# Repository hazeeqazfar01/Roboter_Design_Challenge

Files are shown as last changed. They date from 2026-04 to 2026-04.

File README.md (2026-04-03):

# Roboter Design Challenge 2025 @ Jade Hochschule
https://www.jade-hs.de/unsere-hochschule/fachbereiche/ingenieurwissenschaften/veranstaltungen/design-challenge/

**Team Members:** Isma, Syahir, and Hazeeq

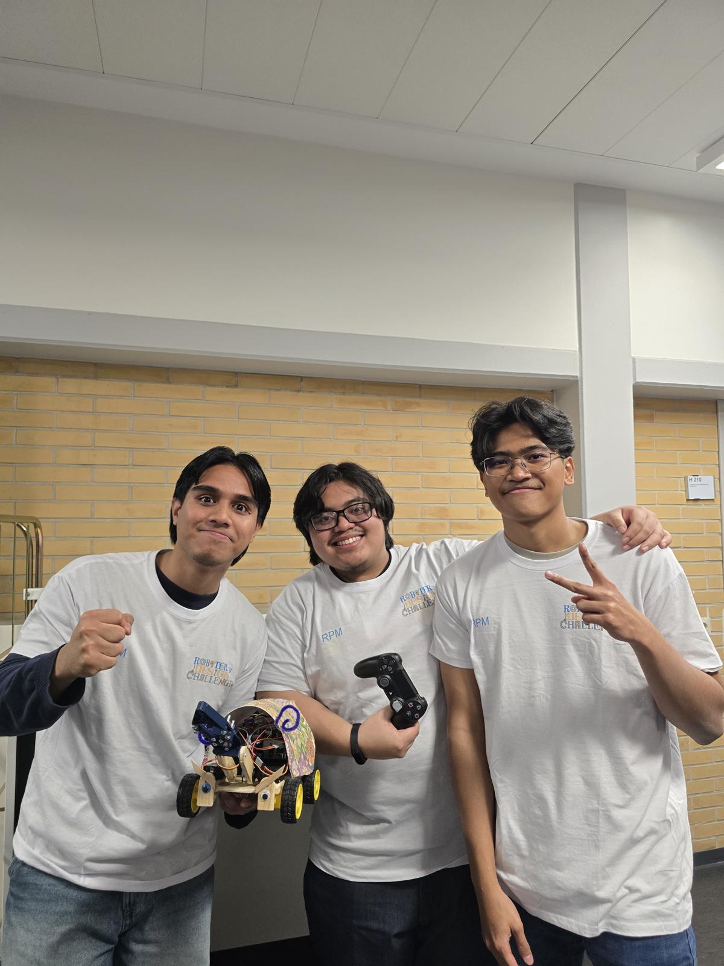
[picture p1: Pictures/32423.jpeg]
Project Picture

---
https://www.nwzonline.de/wilhelmshaven/karrieretag-in-wilhelmshaven-jade-hochschule-begeistert-800-besucher-mit-einblicken-in-studium-und-beruf_a_4,2,2852570350.html#
---

This repository contains documents, project materials, and results from our participation in the **Roboter Design Challenge 2025**.

Dieses Repository enthält Unterlagen, Dokumentationen und Projektergebnisse unserer Teilnahme an der **Roboter Design Challenge 2025**.

---

## Deutsch

### Über den Wettbewerb
Die Roboter Design Challenge 2025 steht unter dem Motto eines Katastrophenszenarios in der Stadt Wilhelmshaven. Ziel ist die Entwicklung und Programmierung eines Roboters, der in einer modellhaften Stadt Hilfs- und Transportaufgaben übernimmt.

### Aufgabenstellung
Die Teams erhalten einen vom Roboter Design Challenge Team bereitgestellten Bausatz, aus dem nach den geltenden Regeln ein funktionsfähiger Roboter konstruiert wird. Bei Bedarf kann der Roboter mit eigenen Teilen ergänzt werden.

### Projektinhalt
Dieses Repository enthält projektbezogene Unterlagen und Dateien aus verschiedenen Arbeitsbereichen, zum Beispiel:
- Entwurfsphasen
- Programmierung
- Report
- Regelwerk
- Weitere Projektdokumente

### Unsere Arbeit
Im Rahmen des Projekts arbeiteten wir an der Planung, Konstruktion, Dokumentation und Organisation des Robotersystems.

---

## English

### About the Competition
The Roboter Design Challenge 2025 is based on a disaster scenario in the city of Wilhelmshaven. The goal is to design and program a robot that can carry out aid and transport tasks in a model city environment.

### Task Description
Each team receives a kit provided by the Roboter Design Challenge team. According to the competition rules, this kit is used to construct a functional robot. If necessary, the robot can be extended with additional custom parts.

### Project Contents
This repository includes project-related documents and files from different work areas, such as:
- Design phases
- Programming
- Report
- Rules and regulations
- Additional project documents

### Our Work
As part of this project, we worked on the planning, construction, documentation, and organization of the robotic system.

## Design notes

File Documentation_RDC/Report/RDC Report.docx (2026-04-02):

Robotic Design Challenge

By RPM

Gruppe | RPM
Gruppenmitglieder (Name, Vorname, Matrikelnummer) | Muhammad Syahir Irshad Bin Mohd Sharuddin - 6056209
| Muhammad Isma Haikal bin Ismail – 6057561
| Muhammad Hazeeq Azfar bin Herman 6055724

# 1. Einleitung

Die Roboter Design Challenge 2025 steht unter dem Motto eines schweren Katastrophenszenarios in der Stadt Wilhelmshaven. Ein Sturm hat große Schäden angerichtet: Stromleitungen sind zerstört, Hilfsgüter müssen schnell geliefert werden und zahlreiche Menschen benötigen medizinische Hilfe.

Die Teams erhalten einen vorgegebenen Bausatz und entwickeln daraus – unter Einhaltung der Regeln – einen funktionsfähigen Roboter, der bei Bedarf mit eigenen Bauteilen erweitert werden darf. Auf einem Spielfeld im Miniaturformat der Stadt müssen die Roboter verschiedene Aufgaben bewältigen.

In den Wettbewerbsrunden stehen drei zentrale Herausforderungen im Mittelpunkt:

- Stromversorgung wiederherstellen: Die Teams müssen eine beschädigte Stromleitung finden und reparieren. Die Bewertung erfolgt nach Zeit.
- Hilfsgütertransport: dringend benötigte Güter werden vom Deich zum Krankenhaus transportiert und korrekt abgelegt. Schnellste Teams bzw. Teams mit den meisten Gütern kommen weiter.
- Personenrettung: Figuren in den Farben Rot, Gelb und Grün – entsprechend dem Manchester Triage System – müssen sicher geborgen und zum Behandlungsplatz gebracht werden. Je nach Dringlichkeit gibt es unterschiedliche Punktzahlen, Bonuspunkte bei besonders schneller Rettung.

Diese Szenarien verlangen ein Robotersystem, das zuverlässig fährt, transportiert, erkennt, greift und Präzisionsaufgaben ausführt – Fähigkeiten, die im Mittelpunkt unseres Projekts stehen.

# 2. Ziel des Projekts

Ziel dieses Projekts ist es, ein Roboter zu entwickeln, das den Anforderungen und Einsatzbedingungen entspricht

Dafür wird eine methodische Vorgehensweise genutzt, die sich an bewährten Schritten im Konstruktionsprozess orientiert. Dazu gehören: das Erstellen einer Anforderungsliste, das Entwickeln einer Funktionsstruktur, das Finden grundsätzlicher Lösungsansätze, die Bewertung möglicher Varianten sowie eine Risikobetrachtung. Diese strukturierte Vorgehensweise sorgt dafür, dass der Roboter passend zur Aufgabenstellung entworfen wird.

# 3. Anforderungsliste

Die Anforderungsliste wurde im Rahmen einer vorgegebenen Aufgabenstellung gemeinsam entwickelt. Die Liste dient als verbindliche Planungsgrundlage für die weitere Ausarbeitung des Entwurfs. Durch die gemeinsame Bearbeitung wurde sichergestellt, dass alle ein einheitliches Verständnis der Anforderungen besitzen und diese im Konstruktionsprozess konsequent berücksichtigt werden.

Tabelle1: Die gemeinsame Aufforderungsliste für den Entwurf

Kategorie | Anforderung | Detail | F/W
FAHREN | • Muss über unebenes Gelände und Rampen (Steigung max.10 Grad) fahren können (Geländegängigkeit). | • Fahrwerk muss stabil sein (gegen Wackeln/Kippen). | F
| • Muss sich in engen Raum drehen und wenden können. | • Darf die Maße 24×19×45 cm niemals überschreiten. | F
GELD/PERSONEN | • Muss die Hilfsgüter−Box und die Personen−Figuren aufnehmen können. | • Der Greifarm/Mechanismus muss präzise genug sein, um kleine Figuren zu fassen. | F
| • Muss die Objekte während der Fahrt sicher halten (Transportschutz). | • Die 3 Servos und 4 Motoren müssen optimal für Bewegung und Greifen genutzt werden. | F
| • Muss die Stromversorgung (Hebel/Schalter) betätigen können. | | F
WETTKAMPF | • Muss sehr zuverlässig sein (damit es wenig Eingriffe gibt: ≤4 Eingriffe erlaubt). | • Die Elektronik muss sicher und einfach zugänglich sein für schnelle Reparaturen. | F
| • Wunsch: Muss schnell genug sein, um alle Personen in ≤6 Minuten zu retten (Bonus!). | | W
PROGRAMMIERUNG | • Die Steuerung muss präzise sein, damit Sie den Roboter gut kontrollieren können. | • durch den Einsatz von ESP32, H-Brücken und Kontroller | F

# 4. Projektablauf

Damit der Entwurf termingerecht und strukturiert ausgearbeitet werden könnte, wurde ein Gantt-Diagramm erstellt. Es dient dazu, den zeitlichen Ablauf des Projekts übersichtlich darzustellen und die einzelnen Arbeitsschritte sowie deren Abhängigkeiten zu planen und zu koordinieren.

Tabelle 2: Der gesamte Projektablauf in der Form Gantt-Diagramm für den Entwurf

Nr. | Vorgangs-name | 13.10 | 15.10 | 18.10 | 20.10 | 20.10 | 23.04 | 26.10 | 28.10 | 29.10 | 06.11 | 9.11 | 10.11 | 15 .11 | 16.11 | 18.11 | 19.11
1 | Bausätze abholen
2 | Phase 1
3 | Projektzeitplan erstellen
4 | Roboter Recherchieren
5 | Lösungen finden
6 | Ideen finalisieren
8 | Phase 2
9 | Schaltplan verstehen
10 | 3D Teil suchen
11 | Löten
12 | Phase 3
13 | Holz bearbeiten
14 | Bauteile kaufen
15 | Anfangen zu programmieren
16 | Roboter konstruieren
17 | Phase 4
18 | Programmierung
19 | Debugging
20 | Dokumentation erstellen
21 | Zulassung für Wettbewerb
22 | Tag des Wettbewerbes

# 5. Mechanisches Konzept und Roboter Komponenten

## 5.1. Aufbau

### Bodenplatte

Sie bildet die zentrale Trägerstruktur des gesamten Roboters. Auf ihr werden alle elektrischen und mechanischen Komponenten befestigt. Sie sorgt für Stabilität, Gewichtsausgleich und eine geordnete Platzierung von Steuerplatine, Versorgungsmodulen, Motoren und Armmechanik. Sie besteht aus Holz, wobei besonders auf Steifigkeit und geringes Gewicht geachtet wird.

### Greifer

Er ist das mechanische Element, das es dem Roboter ermöglicht, Objekte aufzunehmen, festzuhalten und zu transportieren. Er wird meist durch ein oder zwei Servomotoren angetrieben, die für präzise Bewegungen sorgen. Je nach Konstruktion kann der Greifer parallel schließen, klemmen oder zangenartig greifen.

### Roboterarm

Er verbindet die Bodenplatte mit dem Greifer und sorgt dafür, dass dieser in unterschiedliche Positionen bewegt werden kann. Üblicherweise ist der Arm mehrgliedrig aufgebaut, ähnlich wie ein menschlicher Arm mit Schulter-, Ellenbogen- und Handgelenksbewegung. Die Antriebe erfolgen durch Servomotoren oder Getriebemotoren. Der Arm muss leicht genug sein, damit die Motoren nicht überlastet werden, gleichzeitig jedoch steif und stabil, um präzise Bewegungen und eine gewisse Traglast zu gewährleisten.

### Reifen

Sie sind für die Fortbewegung des Roboters verantwortlich. Gummierte oder profilierte Räder sorgen für eine gute Traktion auf verschiedenen Untergründen, während der Durchmesser des Reifens die Geschwindigkeit und die Fähigkeit bestimmt, kleinere Hindernisse zu überwinden. Die Reifen sind direkt oder über eine Getriebeuntersetzung mit den DC-Motoren verbunden, wodurch Antriebskraft und Bewegungspräzision beeinflusst werden.

### Akkupack

Es versorgt alle Komponenten des Roboters zuverlässig mit Energie. Der Akku muss eine ausreichende Kapazität sowie einen ausreichenden Entladestrom bereitstellen, damit Motoren, Servos und Mikrocontroller stabil betrieben werden können. Über die Versorgungsplatine wird die Spannung geregelt und sicher auf die einzelnen Verbraucher verteilt.

## 5.2. Funktion

Der in diesem Projekt entwickelte Robote dient zur gezielten Manipulation von kleinen Objekten in einem vorgebebenen Spielfeld. Er würde im Rahmen eine Design Challenge entworfen, konstruiert und programmiert, um grundlegende Prinzipien von Aktuator- und Elektro- und Steuerungstechnik in der Praxis umzusetzen.

Die Bewegung dieser Roboterarm würden durch Einsetzen mehrere Servomotoren erreicht, die eine präzise Positionierung des Endeffektors ermöglichen. Für dieses Projekt würden zwei SG5010 Servomotoren und eine SG90 Servomotor, die ein ausreichendes Drehmoment liefern, verwendet, damit sowohl leichte Bauteile als auch kleineren Lasten zuverlässig bewegen werden können.

Die Funktionen dieses Motors lassen sich anhand einiger Punkten beschreiben. Diese Funktionen umfassen die für den Challenge vorgegebene Aufgabe sowie einige weitere, die hinzugefügt wurden, um unsere Fähigkeiten in diesen Bereichen weiter auszubauen und zu verfeinern. Die Funktionen lassen sich wie folgt beschreiben:

- Objektaufnahme: Der Greifer öffnet und schließen kontrolliert, um kleine Objekte sicher zu erfassen, ohne zu beschädigen.
- Objekttransport: Der Roboterarm bewegt das gegriffene Objekt mithilfe des Drehgelenks im Roboterarm.
- Objektablage: Das Objekt wird an der gewünschten Position präzise abgelegt, unterstutzt durch die fein gesteuerte Greiferbewegungen.
- Joysticksteuerung (PS4- Controller): Die Taste im Kontrolle steuern alle Bewegungen des Robotes, wie die Vorwärts- und Rückwärtsbewegung, Rotationsbewegung, Drehung des Gelenkes und das Öffnen und Schließen des Greifers.
- Lastaufnahme im vorgesehenen Bereich: kann kleine Werkstücke im Rahmen von 100g Gewicht zuverlässig aufnehmen und stabil halten.
- Funktionssicherheit: Die Elektronik schützt von Fehlerfunktionen wie Überlast oder falscher Motoransteuerung, wodurch ein sicherer Betrieb gewährleistet sind.

In Verbindung mit diesen Funktionen kann das Projekt eine angemessene Richtung in seiner Entwicklung einschlagen und den Fortschritt bis zur Fertigstellung des Projektes beschleunigen. Mit ihrer Hilfe wird der Roboter in einige Hauptfunktion unterteilt, die bei der Entscheidung über die Konstruktion und Bau des Roboters im Mittelpunkt stehen werden.

## 5.3. Handskizzen

Für den Entwurf des Roboters werden verschiedene Lösungen mit unterschiedlicher Charakteristisch hergestellt. Die Vielfalt der Ideen dients als Standarddiskussionsmedium, um die beste und geeignetste Lösung zu finden.

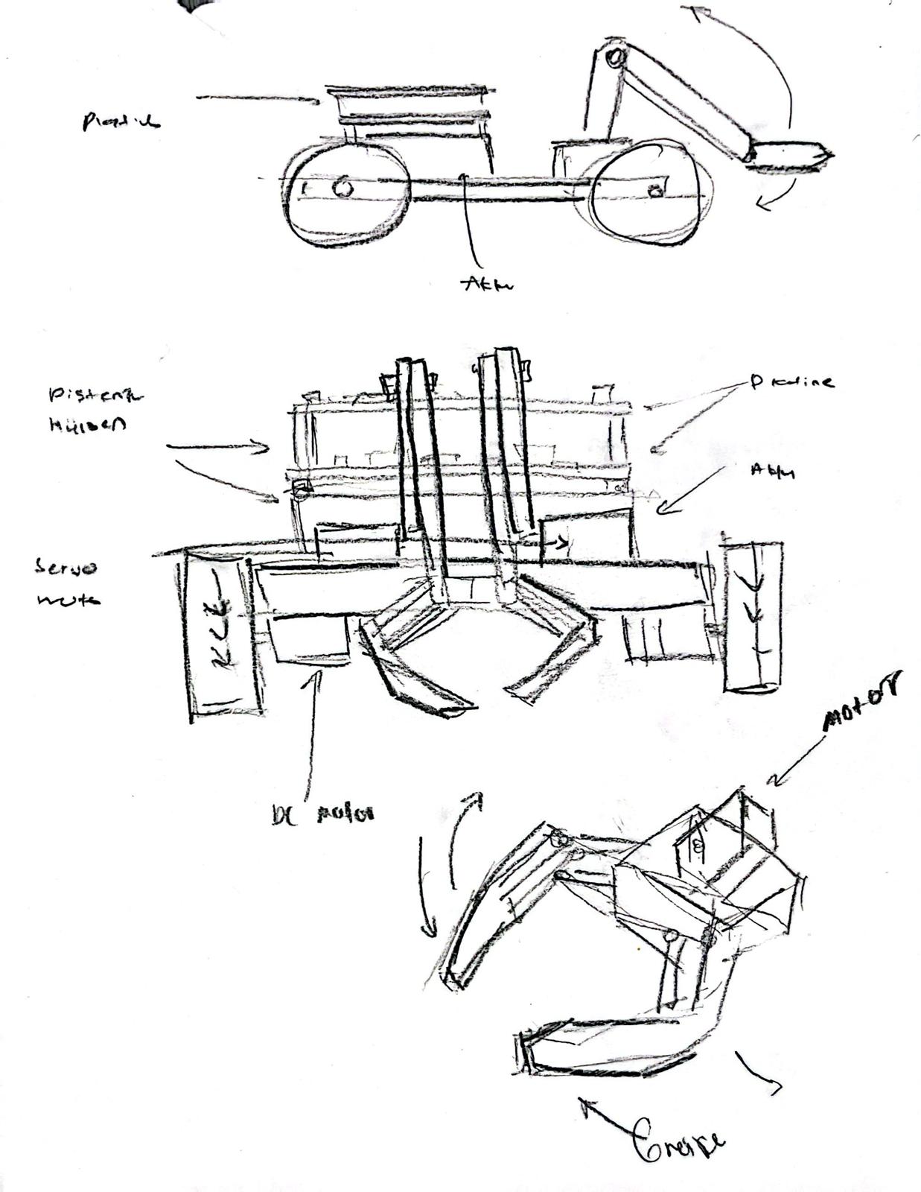
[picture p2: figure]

Abbildung 1: Variante 1

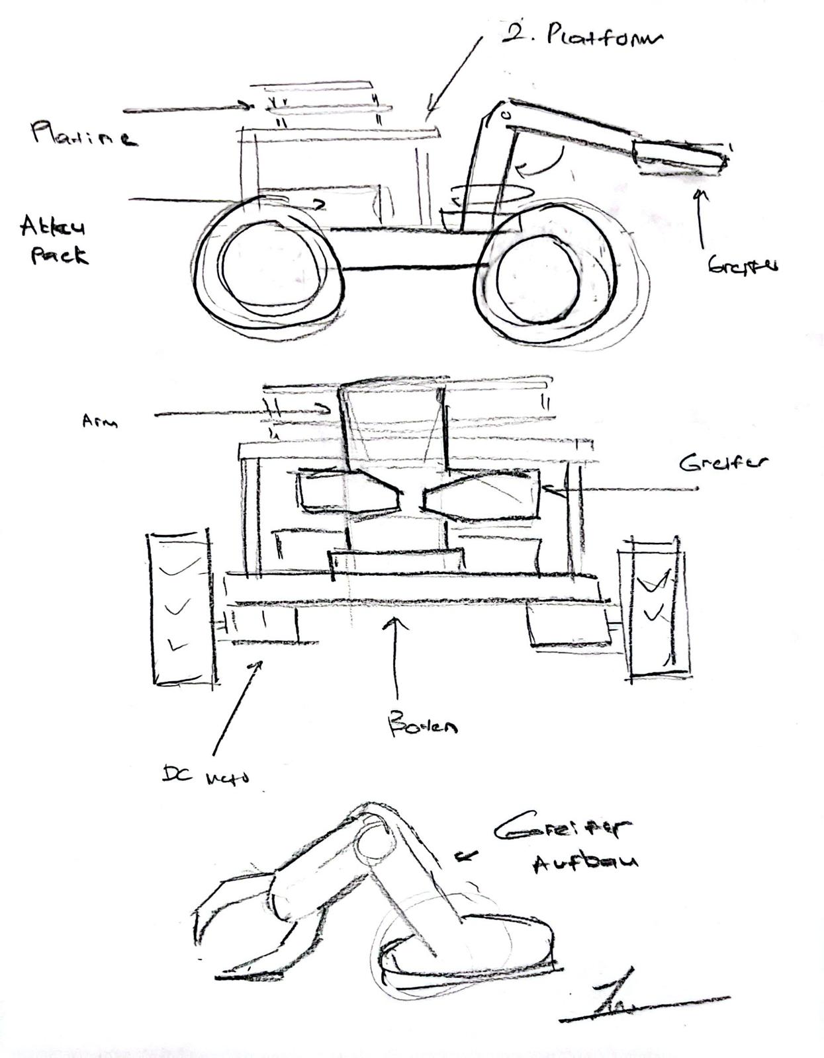
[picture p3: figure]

Abbildung 2: Variante 2

## 5.4. Morphologische Kasten

Tabelle 3: Morphologischer Kasten für die Entscheidung der Lösungen

Teilfunktionen | | Prinzipielle Lösungen/Varianten
| | 1 | 2 | 3
1 | Bewegungs-methode | jeder einzelne Motor | Motor bewegt sich für sich | Motor in paaren
2 | Anzahl der Roboterarm-drehgelenke | 1 | 2 | 3

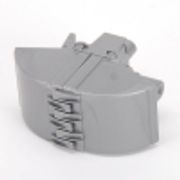
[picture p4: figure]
Bruder Ersatzteile Schaufelgreifer
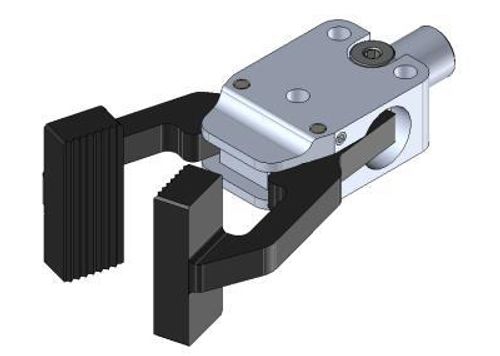
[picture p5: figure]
Greifzange GZA.10.12.AHT , Klemmgroesse 10, lange Greiferbacken in T-Form, Angussgreifzange, FPS EOAT
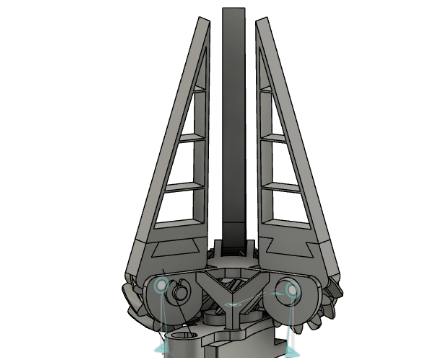
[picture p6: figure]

3 | Greifer-mechanismus | Schaufelgreifer | Zwei-Backen Greifer | Drei-Backen Greifer
4 | Greifermaterial | PLA | ABS | TPE/TPU

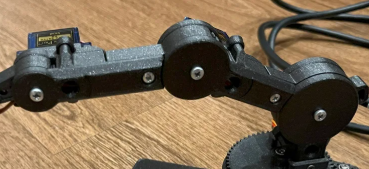
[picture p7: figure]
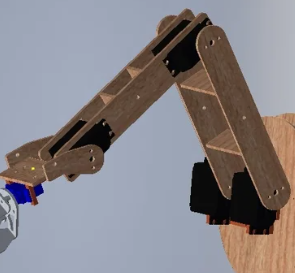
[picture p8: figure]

5 | Roboterarm-mechanismus | Einseitig mit Zahnräder | Einseitig | Zweiseitig
6 | Roboterarm-material | Holz | PLA | Stahl
7 | Gehäusebodenbau | Rechteck | Quadrat | Rechteck mit Abgerundeten Ecken
8 | Gehäuseboden-material | Holz | Karton | Stahl
9 | DC-Motor Steuerung | 1 Controller Joystick | Controller D-Pad | 2 Controller Joystick
10 | Servomotor Steuerung | Controller Gesichtsknöpfe | Controller Trigger-Taste

= Lösung 1 = Lösung 2

## 5.5. Baugruppenstrukturierung

Roboter
(Buggy)
Greiferarm
komplett
Gehäuse
Greifer komplett
Arm komplett
Mechanik
Mechanik
Mechanik
Bodenplatten
Elektronik
Greifer
(3D-Drück-Teile)
Servo Motor
(SG90)
Elektronik
Greifarm
(Holz) x4
Servo Motor
(SG5210) x2
Elektronik
M4 Schrauben
x 6
M4 Mutter
x 6
M4 Schrauben
x 6
M4 Mutter
x 6
Stuhlwinkel
x 2
DC Motor
x 4
Akkupack
Versorgungsplatine
Steuerplatine
Linsenkopfschraube
x4
Distanzhülsen
x 4

Abbildung : Baugruppenstrukturierung des Entwurfs

# 6. Elektronik und Steuerung

## 6.1. Elektronische Komponenten

### Steuerplatine

Die zentrale Hauptplatine, auf der alle Signale zusammenlaufen. Sie verbindet Mikrocontroller, Motoren, Servos und Sensoren miteinander und verteilt die Steuersignale.

### Versorgungsplatine

Platinenbereich oder Modul, das die Stromversorgung übernimmt. Es verteilt die Spannung vom Akku an alle Komponenten und wandelt sie jeweils auf passende Spannungen.

### Mikrokontroller (ESP32)

Das Gehirn des Roboters. Er verarbeitet Eingaben, führt das Programm aus und steuert Motoren, Servos und andere Komponenten über digitale und PWM-Signale.

### Motor Treiber (TB6612FNG)

Eine elektronische Schaltung, die die DC-Motoren antreibt.
Er kann höhere Ströme schalten, ermöglicht Vorwärts/Rückwärtsfahren und regelt die Geschwindigkeit per PWM, da der Mikrocontroller selbst zu schwach wäre.

### Schieberegister (74HC595)

Ein IC, der aus wenigen Mikrocontroller-Pins viele digitale Ausgänge macht. Er wird genutzt, um mehr LEDs, Motoren oder kleine Schaltfunktionen anzusteuern.

### Servomotoren (SG92R & SG5010)

Präzisionsmotoren mit eingebauter Elektronik und Positionsregelung. Sie bewegen den Roboterarm oder Greifer in bestimmte Winkel und sind ideal für genaue Armbewegungen.

### DC-Motoren

Gleichstrommotoren, die das Fahrwerk bewegen. Sie drehen sich vorwärts oder rückwärts und werden über Motor-Treiber geregelt. Ideal für schnelle und kraftvolle Bewegung des Roboters.

## 6.2. Integration der Komponenten in das Gesamtsystem

### Gesamtübersicht

Der Roboter besteht aus zwei zentralen Platinen:

I. Steuerplatine – verarbeitet Signale und steuert alle Aktoren
II. Versorgungsplatine – verteilt die elektrische Energie des Akkus

Alle elektronischen Module werden auf diese beiden Platinen verteilt und miteinander verbunden.

### Steuerplatine

Auf ihr werden der Mikrokontroller, die Motortreiber und die Schieberegister zusammengeführt. Die Steuerplatine übernimmt die Aufgabe, die Steuersignale des Mikrocontrollers aufzubereiten und an die entsprechenden Komponenten weiterzuleiten. Schieberegister ermöglichen es, mehrere Motoren mit nur wenigen Pins anzusteuern, indem sie die digitalen Signale seriell einlesen und parallel ausgeben. Dadurch bleibt der Aufbau kompakt und effizient, selbst wenn viele Verbraucher vorhanden sind. Die Steuerplatine funktioniert somit als logisches Kontrollzentrum, in dem alle Signale organisiert und in die richtige Form für die angeschlossenen Bauteile gebracht werden.

### Versorgungsplatine

Sie verbindet das Akkupack mit den verschiedenen Spannungsreglern und verteilt die benötigten Betriebsspannungen an die Steuerplatine, Motoren und Servos. DC- und Servomotoren benötigen meist eine andere Spannung als der Mikrokontroller, weshalb die Versorgungsplatine mehrere Stromkreise bereitstellt. Zusätzlich sorgt sie dafür, dass Störungen, die von Motoren oder Lastwechseln entstehen, nicht auf die empfindliche Elektronik übertragen werden. Durch diese klare Trennung von Steuer- und Leistungsbereich bleibt das System zuverlässig und verhindert Spannungseinbrüche oder Überlastsituationen.

### Motoren

Die Einbindung der Motoren erfolgt über die Motortreiber, die wiederum mit der Steuerplatine kommunizieren. Die DC-Motoren werden über Motortreiber angesteuert, die sowohl Richtung als auch Geschwindigkeit regeln können. Die Schieberegister liefern dazu die notwendigen digitalen Befehle, die vom Mikrokontroller seriell übermittelt werden. Servomotoren werden hingegen direkt vom Mikrokontroller über PWM-Signale gesteuert, erhalten aber ihre Energie aus der Versorgungsplatine, da sie deutlich höhere Ströme benötigen als ein Mikrokontroller bereitstellen kann. Diese Aufteilung erlaubt es, sowohl kraftvolle DC-Motoren für den Antrieb als auch präzise Servomotoren für den Roboterarm und Greifer gleichzeitig zu betreiben, ohne sich gegenseitig zu stören.

## 6.3. Programmalgorithmen

### Initialisierung

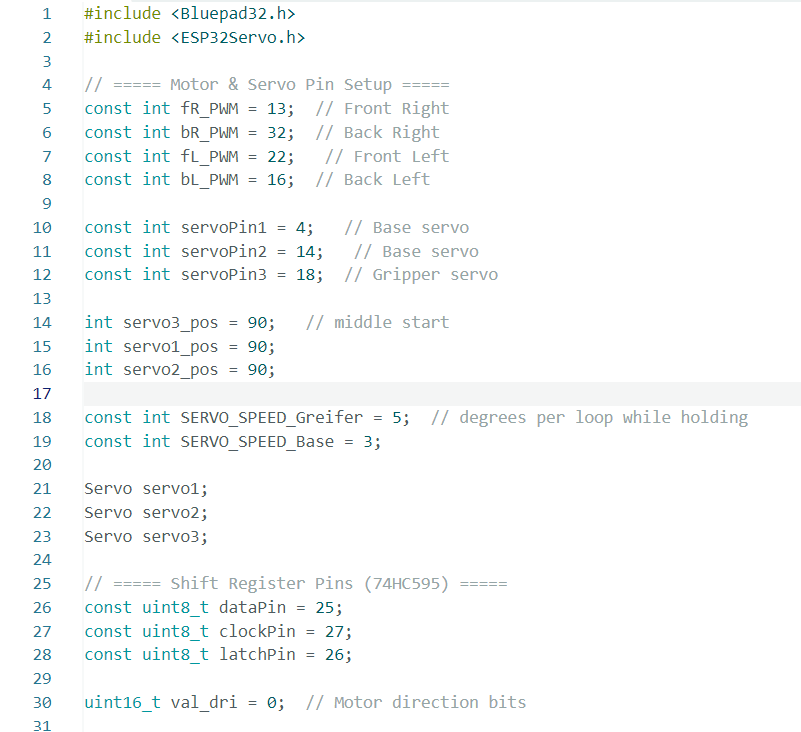
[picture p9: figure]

In diesem Teil sind alle gebrauchten Variablen von den Motoren (Servo-PINs, PWM-PINs und Register-PINs) definiert und mit den passenden PINs an der ESP32 verbindet.

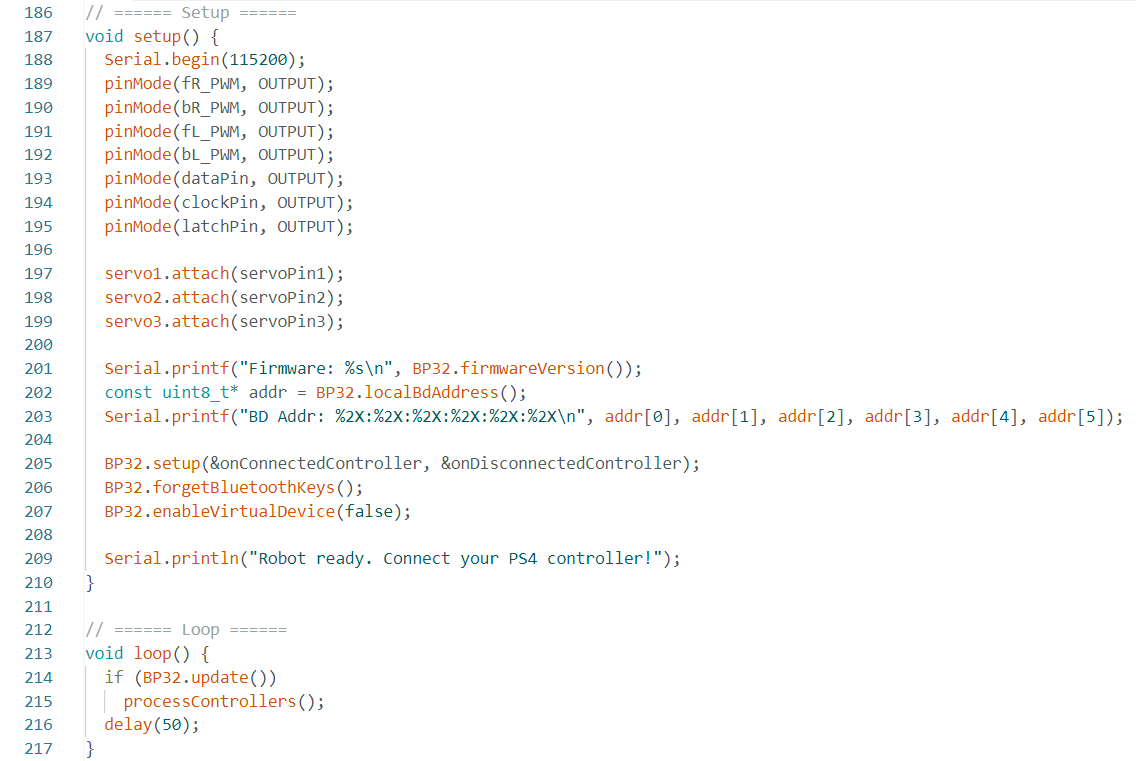
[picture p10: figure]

In diesem Teil wird das Steuerzyklus realisiert und bearbeitet das Aktualisieren von dem Controller pro Zyklus.

### PS4-Controller Verarbeitung

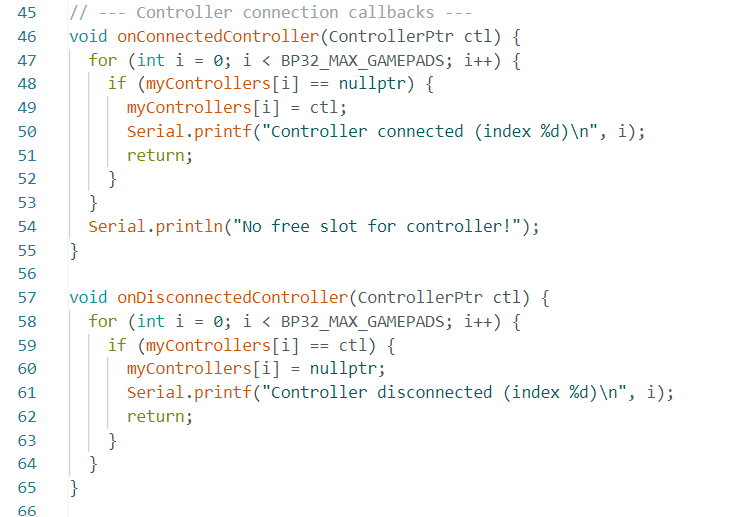
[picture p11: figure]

Hier wird das PS4 Controller via Bluetooth verarbeitet. Damit kann der roboter mit dem Controller verbindet und kontrolliert werden.

### Schieberegister Schreiben

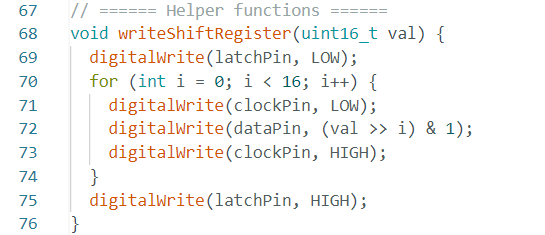
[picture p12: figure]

Hier ist die Funktion von dem zu benutzenden Register-Logik geschrieben werden. Das ermöglicht die Steuerung von viele Eingänge der DC-Motoren mit nur Drei Eingänge an der ESP32 realisiert werden.

### DC- und Servomotorsteuerung

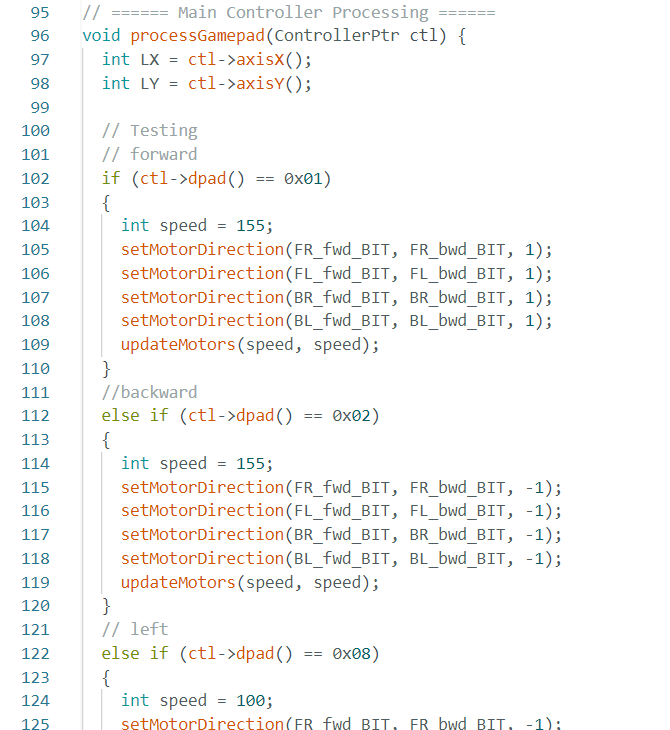
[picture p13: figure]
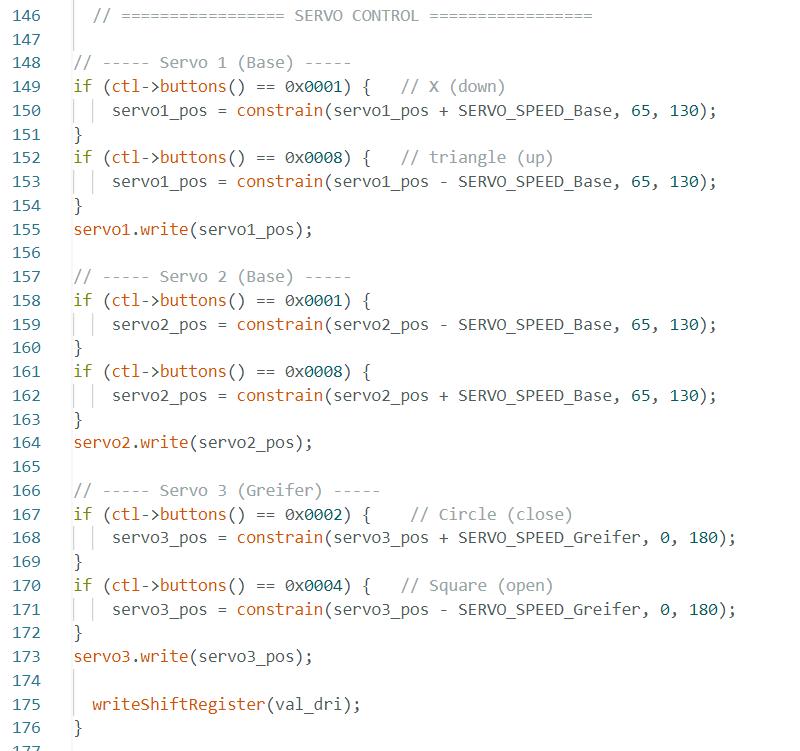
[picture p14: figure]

In diesem Teil ist das Hauptprogrammteil für das Kontrollieren des Roboters mittels der PS4-Controller zu sehen. Hier werden die Bewegungen und Geschwindigkeit von DC-Motoren und Servomotoren mit den verfügbaren Controller-Tasten verbindet:

i. Vorwärts: D-pad oben
ii. Rückwärts: D-pad unten
iii. Nach links: D-pad links
iv. Nach rechts: D-pad rechts
v. Roboterarm hoch: Dreieck-Taste
vi. Roboterarm runter: X-Taste
vii. Greifer öffnen: Viereck-Taste
viii. Greifer schließen: Kreis-Taste

# 7. Zusammenfassung

Im Rahmen der Robotic Design Challenge 2025 wurde ein funktionsfähiger Roboter entwickelt, der die zentralen Aufgaben des Wettbewerbs – Fahren, Greifen, Transportieren und präzise Manipulation – zuverlässig erfüllen kann. Durch eine strukturierte Vorgehensweise mit Anforderungsliste, Funktionsanalyse, Variantenvergleich und mechanischer sowie elektronischer Ausarbeitung entstand ein robustes, praxisorientiertes System.

Der entwickelte Roboter wurde für die Roboter Design Challenge 2025 konstruiert und kombiniert ein robustes Fahrwerk, einen präzisen Greifarm und eine zuverlässige Steuerung über einen PS4-Controller. Die Mechanik besteht aus einer stabilen Bodenplatte, einem mehrgliedrigen Arm und einem servoangetriebenen Greifer. Elektronisch wird der Roboter durch eine getrennte Steuer- und Versorgungsplatine organisiert: Der ESP32 übernimmt die Signalverarbeitung, während Motortreiber und Schieberegister die DC-Motoren ansteuern und die Versorgungsplatine alle Komponenten sicher mit Energie versorgt. Die Software verbindet sämtliche Module zu einem funktionsfähigen System, das sich präzise bewegen, Objekte greifen und transportieren kann.

Insgesamt zeigt das Projekt, dass eine systematische technische Herangehensweise – kombiniert mit praktischer Umsetzung in Mechanik, Elektronik und Software – zu einem leistungsfähigen Robotersystem führt, das die Anforderungen des Wettbewerbs erfüllt und eine solide Grundlage für weitere Verbesserungen bietet.

# 8. Anhang

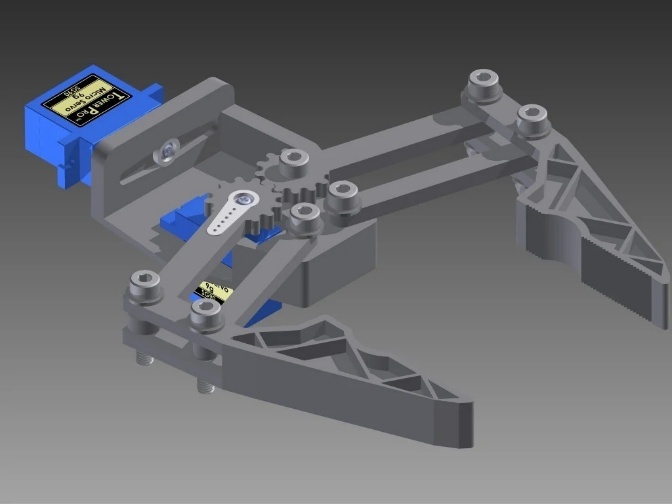
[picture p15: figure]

3D-Model des Greifers

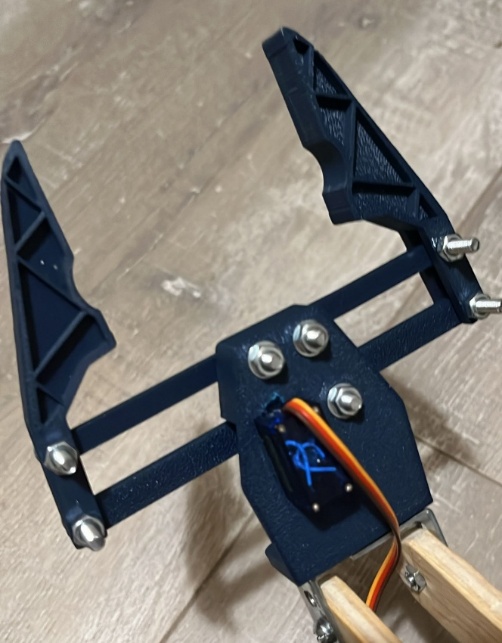
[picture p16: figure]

Greifer nach dem Drucken mit Gewicht von 30g

Quelle: https://www.thingiverse.com/thing:715525

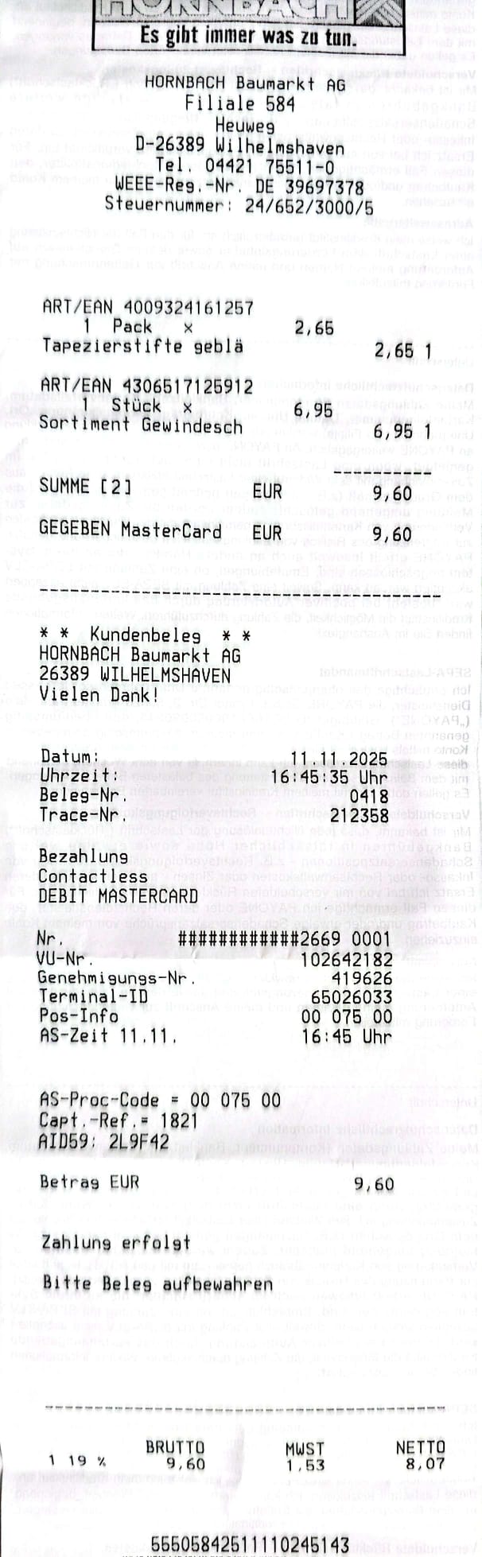
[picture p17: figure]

Quittung der eingekauften Teilen

Bericht für das Roboter Design Challenge 16.11.2025

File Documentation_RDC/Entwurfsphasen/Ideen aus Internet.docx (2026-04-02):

Ideen aus Internet

1)“Stagbeetle“

Inspiration aus Natur

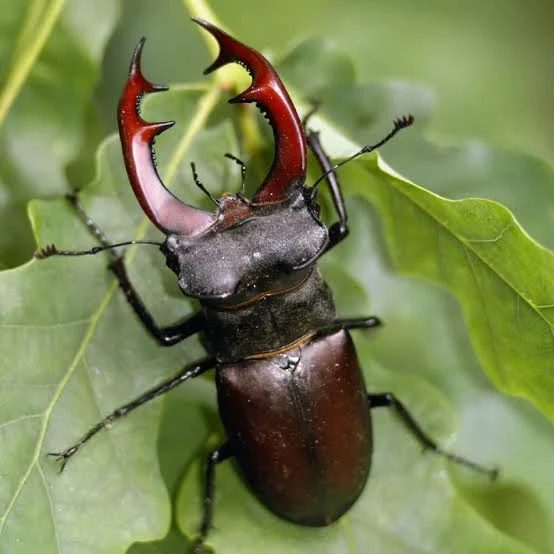
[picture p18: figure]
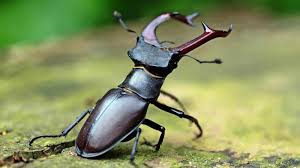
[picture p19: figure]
Stag Beetle: How to Identify and ...

Beispiele:

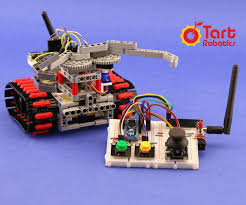
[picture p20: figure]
A DIY Rescue Robot With Arduino, 3D ...

Webseite:

https://www.instructables.com/A-DIY-Rescue-Robot-With-Arduino-Lego-and-3D-Printe/

Youtube:

https://www.youtube.com/watch?v=l-v2fgkYPig

2)“Scorpion“

Inspiration aus Natur:

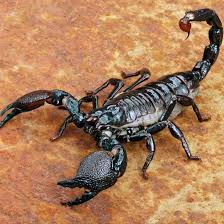
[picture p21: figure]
Wie viel wissen Sie über Scorpions ...

Beispiel

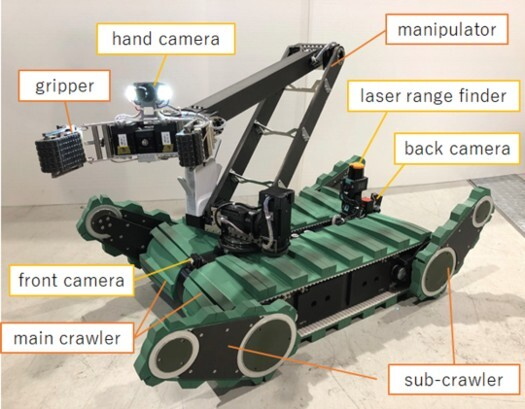
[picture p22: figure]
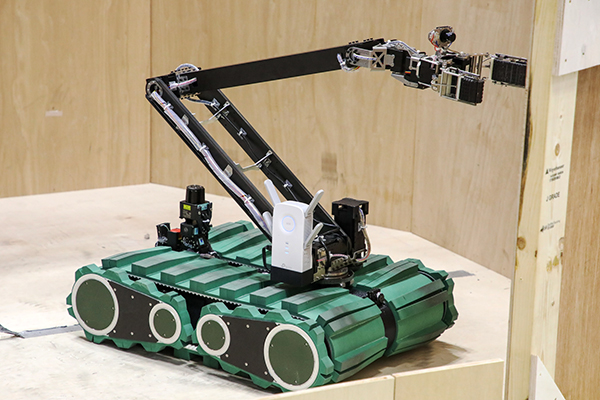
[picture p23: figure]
Discount robocup rescue 2018 Cheap Sale
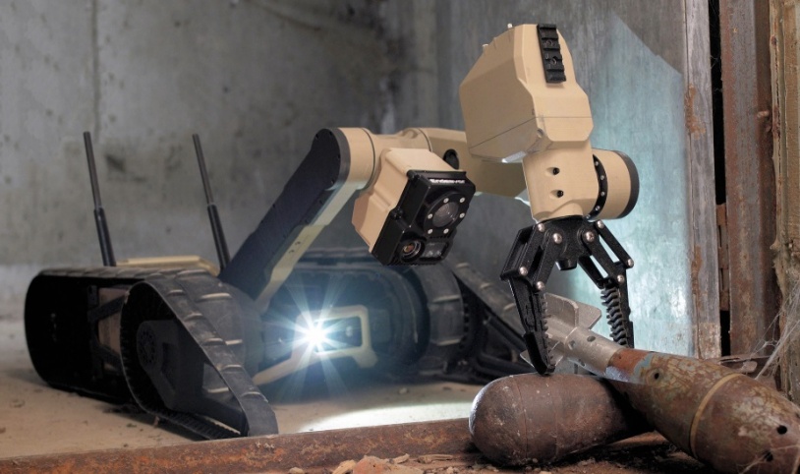
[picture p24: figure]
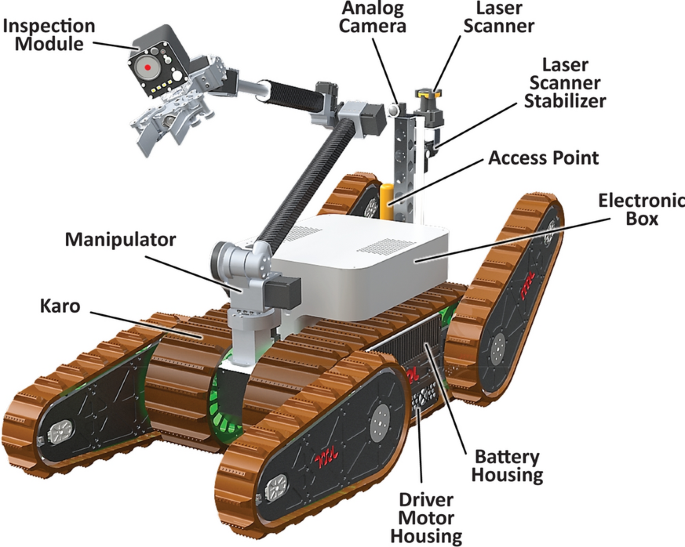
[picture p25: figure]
figure 6

https://robomechjournal.springeropen.com/articles/10.1186/s40648-020-00188-9#Sec7

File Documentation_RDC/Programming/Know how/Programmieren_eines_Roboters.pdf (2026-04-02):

# RDC Academy

Programmieren von Robotern

## Inhalte

- Arduino DIE
- Beispiel: Bluepad32 Controller
- Controller verbinden
- Häufige Fehler

## Arduino IDE

- Libraries hinzufügen
- File → Preference → Additional Boards Manager URLs
- Einfügen:
- https://raw.githubusercontent.com/espressif/arduino-esp32/ghpages/package_esp32_index.json


- https://raw.githubusercontent.com/ricardoquesada/esp32-arduino-libbuilder/master/bluepad32_files/package_esp32_bluepad32_index.json


## Arduino IDE

- Arduino IDE öffnen
- Menü am Rand Boards Manager auswählen
- Im Suchfeld „ESP32“ eingeben
- Passendes Paket „ ESP32 by Espressif“ auswählen
- Auf „Installieren“ klicken

## Arduino IDE


- Arduino IDE öffnen
- Menü am Rand Boards Manager auswählen
- Im Suchfeld „Bluepad32“ eingeben
- Passendes Paket „Bluepad32 for ESP32“ auswählen
- Auf „Installieren“ klicken

## Arduino IDE

- Überspielen der Daten
- Oben links: „Verifizieren“ und „Hochladen“
- Board auswählen auf einer der COM-Schnittstellen

## Beispiel: Bluepad32 Controller

- Controller Beispiel:
File → Exempels → Bluepad32_ESP32 → Controller


- Erkennen und Verbinden von Controllern

•Abfragen von Joystick- und Buttonwerten

## Beispiel Controller verbinden

- Programm ist auf dem Stick
- Zeigt, wie sich nur ein bestimmter Controller verbinden kann.

## Schieberegister

- Aufbau vom Register
- Alle Register werden von vorne bis hinten beschrieben
- Clock pin = low -> ermöglicht das Einschieben, im Takt des Flankenwechsels
- Data pin -> der eigentliche Bitwert wird übergeben
- Latch pin = high -> macht die temporären Zustände zu permanenten Ausgängen
- Aufbau vom Register
- Alle Register werden von vorne bis hinten beschrieben
- Clock pin = low -> ermöglicht das Einschieben, im Takt des Flankenwechsels
- Data pin -> der eigentliche Bitwert wird übergeben
- Latch pin = high -> macht die temporären Zustände zu permanenten Ausgängen


## Programmverwendung

- Übergabe eines 16-/8-Bit Binärwertes
- __register_write_drivers__(0b01111000011110000)
- __register_write_leds__(0b01010101)


## Testprogramm

- Testprogramm mit Controller das die LEDs steuert

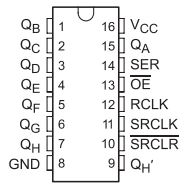
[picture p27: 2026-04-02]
Documentation_RDC/How to get started/Platine/74hc595-pinout.jpg

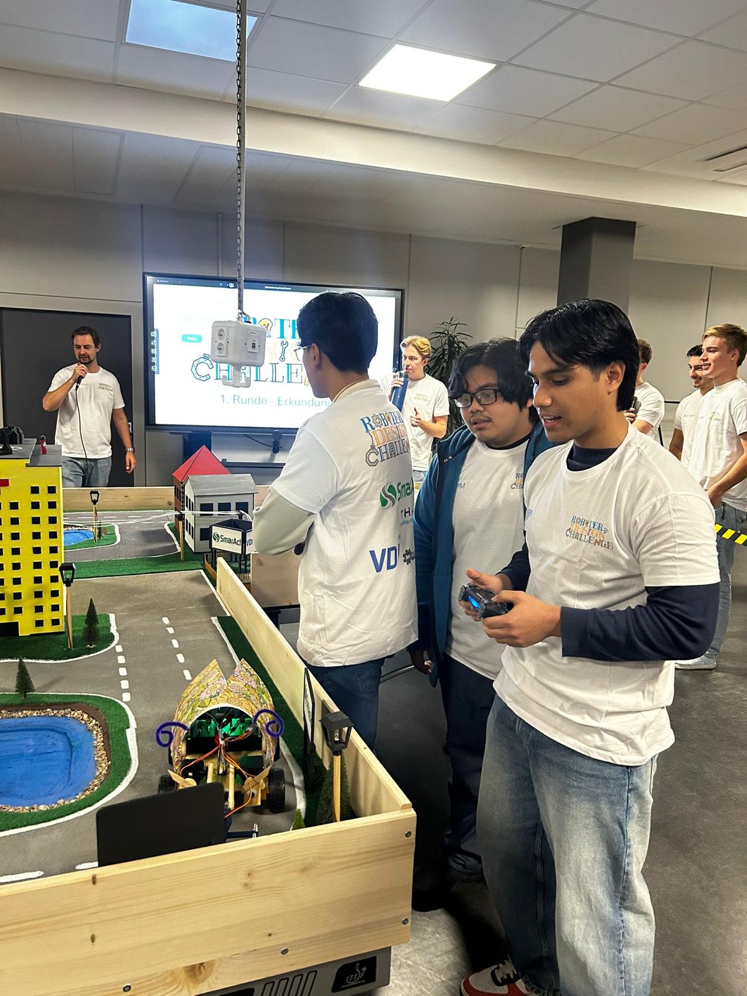
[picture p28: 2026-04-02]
Pictures/9wdw.jpeg

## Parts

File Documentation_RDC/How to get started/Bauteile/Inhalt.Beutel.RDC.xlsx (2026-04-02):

Beutel No. | Quantity | Item Description (German) | Item Description (English Translation) | Notes / Specifications
1 | 2x | Sicherungshalter | Fuse Holder | 6,3 A, 250 V
1 | 2x | Kappe für Sicherungshalter | Cap for Fuse Holder | transparent
1 | 1x | Feinsicherung | Fine Fuse | 1:00:00
1 | 1x | Feinsicherung | Fine Fuse | 2:00:00
1 | 2x | Eibaukupplung Lötstifte | Installation Coupling Solder Pins | 12 V, 5 A
1 | 2x | Gleichrichterdiode | Rectifier Diode | 400 V, 1 A
1 | 2x | Schiebeschalter | Slide Switch | -
2 | 1x | Spannungsregler | Voltage Regulator | 5 V
2 | 1x | Kühlkörper | Heat Sink | clip-on (aufsteckbar)
2 | 1x | Elko | Electrolytic Capacitor | 100 nF
2 | 1x | Elko | Electrolytic Capacitor | 330 nF
3 | 1x | Spannungsregler | Voltage Regulator | 3,3 V
3 | 1x | Elko | Electrolytic Capacitor | 100 nF
3 | 1x | Elko | Electrolytic Capacitor | 10 μF
4 | 5x | Zylinderschraube | Cylinder Screw | M3x20 mm, Stainless Steel (Edelstahl)
4 | 5x | M3 Sicherungsmuttern | M3 Self-locking Hex Nuts | Hexagon, self-locking (Sechskant selbstsichernd)
4 | 10x | Stuhlwinkel | Chair Angle Bracket | 25x25x14 mm (Quantity 10 is handwritten over 6)
5 | 4x | Linsenkopfschraube | Pan Head Screw | M3x6 mm, cross slot (Kreuzschlitz)
5 | 4x | Distanzhülsen | Spacers / Distance Sleeves | Metal (Metall)
6 | 2x | Hohlstecker gewinkelt | Right-Angle Barrel Connector | -
6 | 2x | Molex Stiftleiste | Molex Pin Header | 2x3-pin
6 | 2x | Molex Crimpgehäuse | Molex Crimp Housing | 2x3-pin
6 | 12x | Molex Crimpkontakt Buchse | Molex Crimp Contact Socket | (Question mark handwritten)
6 | 2x | JST Stiftleiste gewinkelt | Right-Angle JST Pin Header | -
6 | 2x | JST Buchsengehäuse | JST Socket Housing | 1x5
6 | 10x | JST Crimp Kontakt Buchse | JST Crimp Contact Socket | (Question mark handwritten)
7 | 4x | LED grün | Green LED | 3,3 V
7 | 3x | LED gelb | Yellow LED | 2,3 V
7 | 1x | LED rot | Red LED | 2,3 V
7 | 1x | Schieberegister | Shift Register | 2−6 V
7 | 1x | IC-Sockel 16-polig | 16-pin IC Socket | Double spring contact (doppelter Federkontakt), Metal
7 | 4x | Widerstand 120 Ω | Resistor 120 Ω | Carbon Film (Kohleschicht)
7 | 4x | Widerstand 100 Ω | Resistor 100 Ω | Carbon Film (Kohleschicht)
8 | 2x | Widerstand 1 kΩ | Resistor 1 kΩ | Metal Film (Metallschicht)
8 | 2x | Widerstand 3 kΩ | Resistor 3 kΩ | Metal Film (Metallschicht)
9 | 4x | Doppelte H-Brücke | Dual H-Bridge | -
9 | 2x | Schieberegister | Shift Register | 2−6 V
9 | 2x | IC-Sockel 16-polig | 16-pin IC Socket | Double spring contact (doppelter Federkontakt)
10 | 4x | LED grün | Green LED | 3,3 V
10 | 1x | Widerstand 120 Ω | Resistor 120 Ω | Carbon Film (Kohleschicht), Metal (Metall handwritten)
10 | 1x | Widerstand 300 Ω | Resistor 300 Ω | Carbon Film (Kohleschicht)
10 | 1x | Widerstand 620 Ω | Resistor 620 Ω | Carbon Film (Kohleschicht)
10 | 1x | Widerstand 1 kΩ | Resistor 1 kΩ | Carbon Film (Kohleschicht)
11 | 1x | Buchsenleiste trennbar | Breakaway Female Pin Header | gold-plated (vergoldet)
11 | 12x | Lötbare Schraubklemme | Solderable Screw Terminal | -
11 | 20x | Stiftleisten gerade | Straight Pin Headers | -
12 | 5x | Gummibänder | Rubber Bands | -
12 | 25x | Büroklammern | Paper Clips | -
12 | 20x | Zahnstocher | Toothpicks | -
12 | 6x | Holzsticks | Wooden Sticks | (Quantity 6 is handwritten over 12)
12 | 20x | Kabelbinder | Cable Ties | -
12 | 2x | Tiefkühletiketten | Freezer Labels | -
12 | 1x | Wackelaugen | Googly Eyes | -
12 | 1x | Magnet | Magnet | -
13 | 8x | Buchsenleiste 1x8 gerade | Straight 1x8 Female Pin Header | -
13 | 8x | Kurzschlussbrücke rot | Red Short Circuit Jumper | with handle tab (mit Grifflasche)

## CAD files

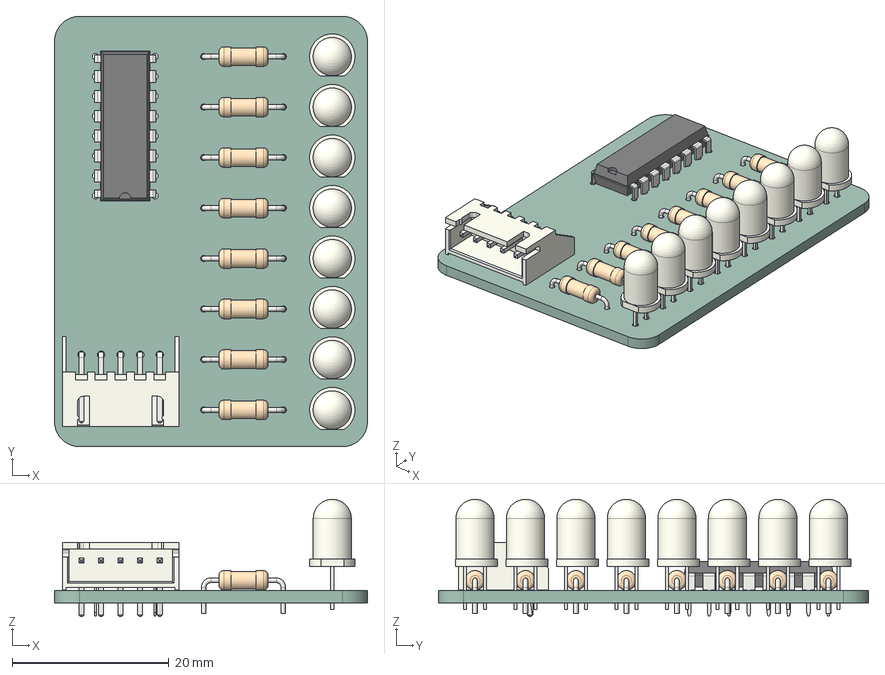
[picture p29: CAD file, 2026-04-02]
Documentation_RDC/How to get started/Platine/led-array_rev1.step
40.0 x 55.0 x 15.0 mm
LED_D5.0mm_Clear x 8
R_Axial_DIN0207_L63mm_D25mm_P1016mm_Horizontal x 8
DIP-16_W7.62mm
JST_S5B_XH_A
LED-Array_PCB

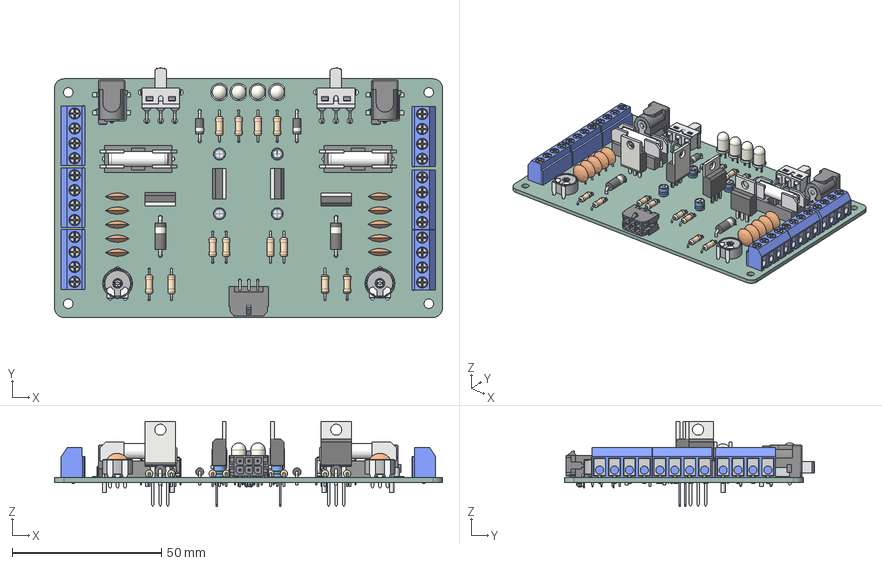
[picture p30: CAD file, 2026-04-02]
Documentation_RDC/How to get started/Platine/versorgungsplatine_rev1.step
130.0 x 83.8 x 28.5 mm
C_Disc_D80mm_W25mm_P500mm x 10
R_Axial_DIN0207_L63mm_D25mm_P1016mm_Horizontal x 12
D_5W_P12.70mm_Horizontal x 2
Screw Terminal Block 5mm Blue 4-way v1 x 6
CP_Radial_D40mm_P150mm x 4
430450600 v2
pin_001 x 2
pin_002 x 2
Chamfer_Holder x 2
Fillet_Fuse x 2
Cut002_Base x 2
TO-220-3_Vertical x 4
P:\E-Switch Secure\3D_MODELS_STP_FORMAT\500SSPxS2M6xEA.stp x 2
LED_D5.0mm_Clear x 4
D_DO-41_SOD81_P10.16mm_Horizontal x 2
Versorgungsplatine_PCB

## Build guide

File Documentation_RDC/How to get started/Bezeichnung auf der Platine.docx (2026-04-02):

Bezeichnung auf der Platine (Position) | Benötigtes Bauteil (aus Beuteln) | Zweck
J1 (unten Mitte) | Stiftleiste (3-polig) | Für die Kommunikationsverbindung zur Steuerplatine (i.d.R. GND, 5V, VBat-Messung).
J2, J3, J4, J5, J6, J7 (blau) | Schraubklemmen (Terminal Blocks) | Ein- und Ausgänge: Hier wird der Akkupack angeschlossen (J2/J7) und hier kommen die geregelten 5V/3,3V heraus.
SW1 / SW2 (oben) | Kippschalter/Taster | Hauptschalter: Schaltet die gesamte Platine ein und aus.
DC-Buchse (oben links) | Hohlsteckerbuchse | Alternative oder Haupt-Eingang für die Versorgungsspannung/den Akku.

Export to Sheets

Schritt 2: Schutzschaltungen (Links und Rechts oben) LÖTEN

Diese Komponenten sorgen dafür, dass die Elektronik (insbesondere der ESP32) nicht durch Verpolung oder Überspannung zerstört wird.

Bezeichnung auf der Platine (Position) | Benötigtes Bauteil (aus Beuteln) | Zweck
T1 / T2 | Sicherungshalter (T-Form) | Hier wird die Schmelzsicherung eingesetzt, um die Schaltung vor Überstrom/Kurzschluss zu schützen.
D1 / D2 (neben SW1/SW2) | Diode (meist SMD oder klein bedrahtet) | Verpolungsschutz: Verhindert Schäden, wenn der Akku falsch herum angeschlossen wird.
D7, D9, D10, D8 (Mitte oben) | LEDs (Leuchtdioden) | Statusanzeige: Zeigen an, ob die jeweiligen Spannungen (3.3V, 5V) aktiv sind und ob die Sicherung ausgelöst hat. Achten Sie auf die Polarität!
R7, R13, R14, R8 | Vorwiderstände (für die LEDs) | Begrenzen den Strom, der durch die LEDs fließt

3. Phase: Spannungsregelung & Hauptfunktion LÖTEN

Diese Bereiche sind die "Herzkammer" der Platine, da sie die Akkuspannung (z.B. 7,4V oder 12V) in die benötigten 5V und 3,3V umwandeln.

Bezeichnung auf der Platine (Position) | Benötigtes Bauteil (aus Beuteln) | Zweck
U1 (links Mitte) | Spannungsregler / DC-DC-Modul (SMD) | Regelt auf 5V. Liefert die stabile Spannung für Servos, Motortreiber und die 3,3V-Schaltung.
U2 (rechts Mitte) | Spannungsregler / DC-DC-Modul (SMD) | Regelt auf 3,3V. Liefert die stabile Spannung, die der ESP32 benötigt.
C1 bis C14 (diverse Plätze) | Kondensatoren | Spannungsglättung: Speichern Energie kurzzeitig und filtern Störungen heraus. Wichtig für stabile Funktion.
R1, R2, R3, R4 (unten) | Widerstände (Spannungsteiler) | Akkuspannungs-Messung: Reduzieren die hohe Akkuspannung auf einen messbaren Wert (max. 3,3V), der in den ESP32-Pin (D39/D36) eingespeist werden kann.
D5, D6, D3, D4 | Dioden/Zenerdioden | Dienen oft als Teil der Schutzschaltung (Überspannungsschutz) oder der Verpolungserkennung

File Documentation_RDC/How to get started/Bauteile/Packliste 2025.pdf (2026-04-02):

Bezeichnung | Menge | Check | Bezeichnung | Menge | Check
Beutel 01 | 1 stk. | ⃝ | Beutel 01 | 1 stk. | ⃝
Beutel 02 | 1 stk. | ⃝ | Beutel 02 | 1 stk. | ⃝
Beutel 03 | 1 stk. | ⃝ | Beutel 03 | 1 stk. | ⃝
Beutel 04 | 1 stk. | ⃝ | Beutel 04 | 1 stk. | ⃝
Beutel 05 | 1 stk. | ⃝ | Beutel 05 | 1 stk. | ⃝
Beutel 06 | 1 stk. | ⃝ | Beutel 06 | 1 stk. | ⃝
Beutel 07 | 1 stk. | ⃝ | Beutel 07 | 1 stk. | ⃝
Beutel 08 | 1 stk. | ⃝ | Beutel 08 | 1 stk. | ⃝
Beutel 09 | 1 stk. | ⃝ | Beutel 09 | 1 stk. | ⃝
Beutel 10 | 1 stk. | ⃝ | Beutel 10 | 1 stk. | ⃝
Beutel 11 | 1 stk. | ⃝ | Beutel 11 | 1 stk. | ⃝
Beutel 12 | 1 stk. | ⃝ | Beutel 12 | 1 stk. | ⃝
Beutel 13 | 1 stk. | ⃝ | Beutel 13 | 1 stk. | ⃝
LED-Array | 1 stk. | ⃝ | LED-Array | 1 stk. | ⃝
Versorgungsplatine | 1 stk. | ⃝ | Versorgungsplatine | 1 stk. | ⃝
Steuerplatine | 1 stk. | ⃝ | Steuerplatine | 1 stk. | ⃝
ESP32 | 1 stk. | ⃝ | ESP32 | 1 stk. | ⃝
Akkupack | 1 stk. | ⃝ | Akkupack | 1 stk. | ⃝
Ladegerät | 1 stk. | ⃝ | Ladegerät | 1 stk. | ⃝
Motor mit Getriebe | 4 stk. | ⃝ | Motor mit Getriebe | 4 stk. | ⃝
Rad | 4 stk. | ⃝ | Rad | 4 stk. | ⃝
Controller | 1 stk. | ⃝ | Controller | 1 stk. | ⃝
Servo SG92R | 1 stk. | ⃝ | Servo SG92R | 1 stk. | ⃝
Servo SG5010 | 2 stk. | ⃝ | Servo SG5010 | 2 stk. | ⃝
Steckerbrückenkabel Set | 2 stk. | ⃝ | Steckerbrückenkabel Set | 2 stk. | ⃝
Vierkantrohr Alu | 1 stk. | ⃝ | Vierkantrohr Alu | 1 stk. | ⃝
Sperrholz Kiefer (240x300x8) | 1 stk. | ⃝ | Sperrholz Kiefer (240x300x8) | 1 stk. | ⃝
ABS Platte 400x250x1 | 1 stk. | ⃝ | ABS Platte 400x250x1 | 1 stk. | ⃝
Holzleim 75 g | 1 stk. | ⃝ | Holzleim 75 g | 1 stk. | ⃝
Sekundenkleber 4 g | 1 stk. | ⃝ | Sekundenkleber 4 g | 1 stk. | ⃝
Maurerschnur 2,5m | 2,5 m | ⃝ | Maurerschnur 2,5m | 2,5 m | ⃝
Isolierband | 1 stk. | ⃝ | Isolierband | 1 stk. | ⃝
Pfeifenreiniger | 11 stk. | ⃝ | Pfeifenreiniger | 11 stk. | ⃝
Häkelgarn | 22 m | ⃝ | Häkelgarn | 22 m | ⃝
Schwamm | 1 stk. | ⃝ | Schwamm | 1 stk. | ⃝
Modelliermasse | 1 stk. | ⃝ | Modelliermasse | 1 stk. | ⃝

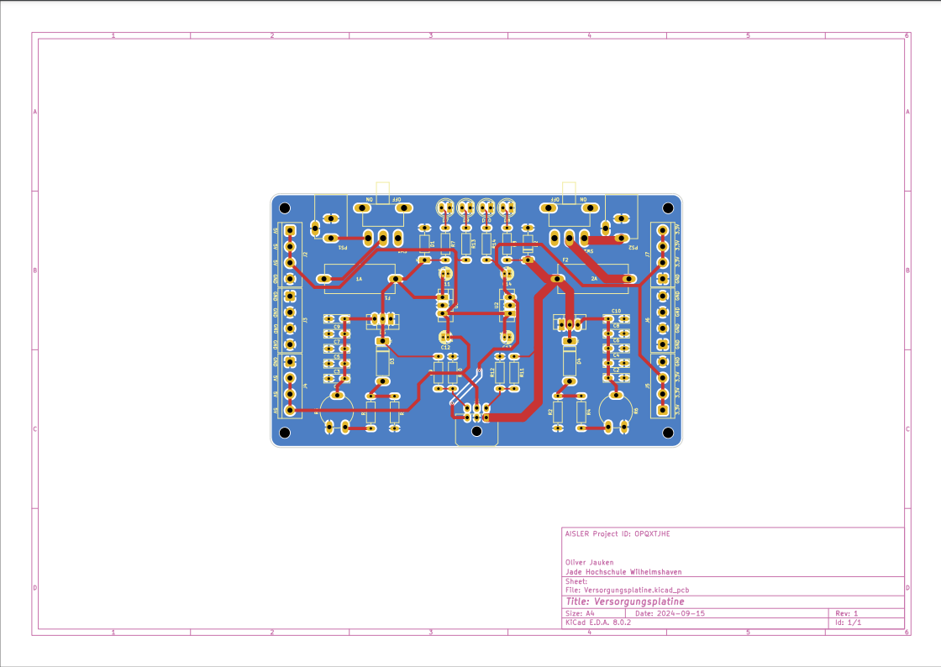
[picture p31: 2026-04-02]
Documentation_RDC/How to get started/Platine/versorgungsplatine.png

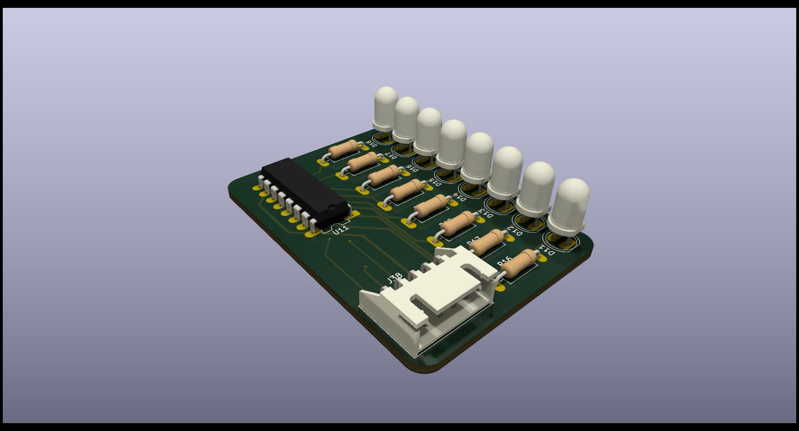
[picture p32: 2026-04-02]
Documentation_RDC/How to get started/Platine/led-array_rev1.jpg

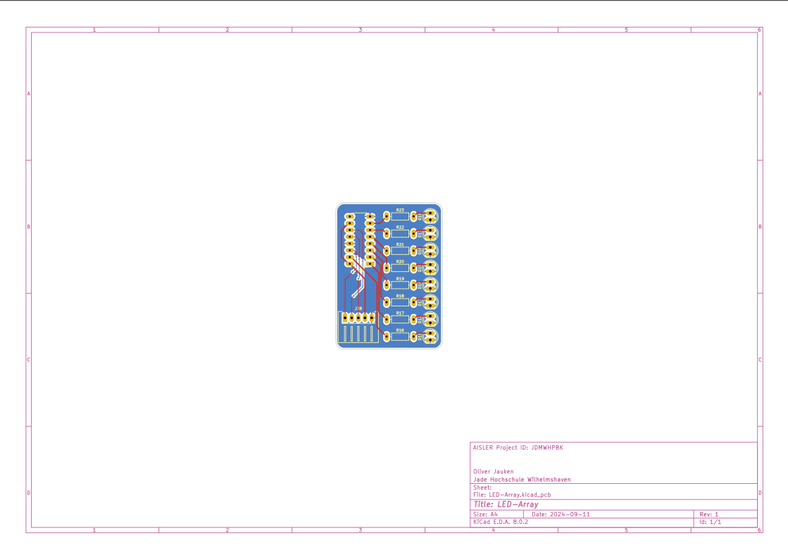
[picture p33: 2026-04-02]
Documentation_RDC/How to get started/Platine/led-array.png

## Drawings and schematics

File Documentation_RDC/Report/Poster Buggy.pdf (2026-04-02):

# BUGGY/bʌ.ɡi/ TEAM: RPM

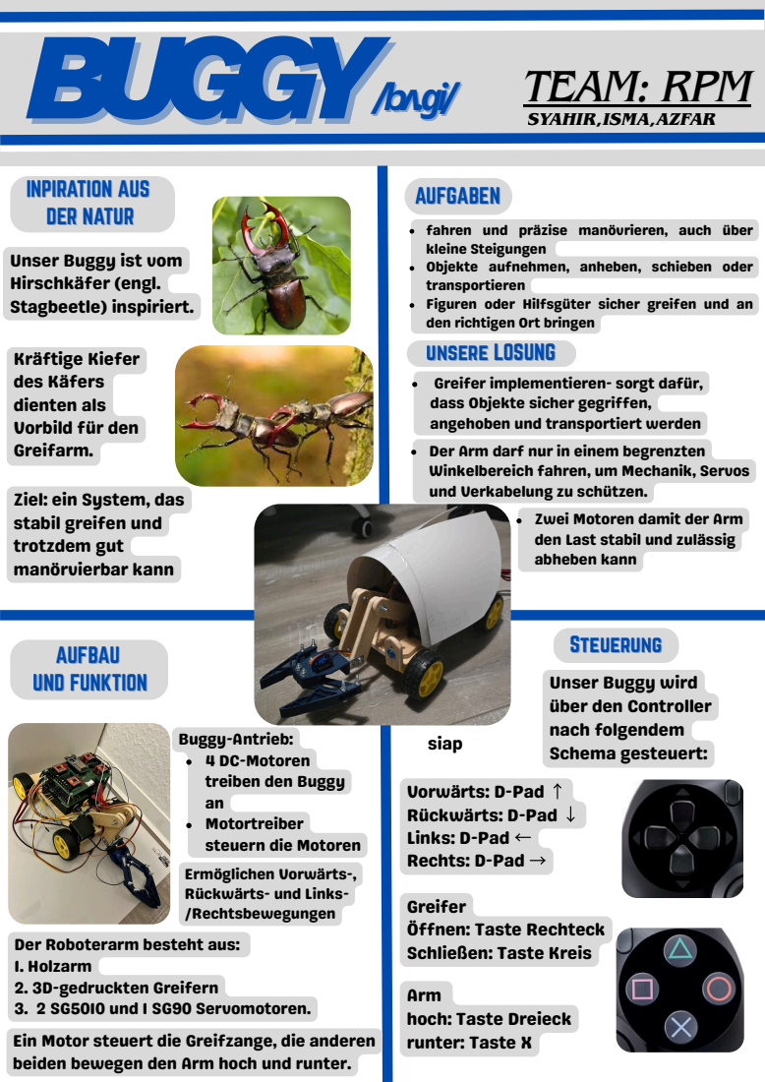
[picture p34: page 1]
INPIRATION AUS DER NATUR; AUFGABEN; AUFBAU UND FUNKTION; Steuerung; Vorwärts: D-Pad ↑ Rückwärts: D-Pad ↓ Links: D-Pad ← Rechts: D-Pad →; siap

SYAHIR,ISMA,AZFAR

fahren und präzise manövrieren, auch über
kleine Steigungen
Objekte aufnehmen, anheben, schieben oder
transportieren
Figuren oder Hilfsgüter sicher greifen und an
den richtigen Ort bringen
unsere LOSUNG
Greifer implementieren- sorgt dafür,
dass Objekte sicher gegriffen,
angehoben und transportiert werden
Der Arm darf nur in einem begrenzten
Winkelbereich fahren, um Mechanik, Servos
und Verkabelung zu schützen.

Unser Buggy ist vom
Hirschkäfer (engl.
Stagbeetle) inspiriert.

Kräftige Kiefer
des Käfers
dienten als
Vorbild für den
Greifarm.

Ziel: ein System, das
stabil greifen und
trotzdem gut
manörvierbar kann

Zwei Motoren damit der Arm
den Last stabil und zulässig
abheben kann

Unser Buggy wird
über den Controller
nach folgendem
Schema gesteuert:

Buggy-Antrieb:
4 DC-Motoren
treiben den Buggy
Motortreiber
steuern die Motoren
Ermöglichen Vorwärts-,
Rückwärts- und Links-
/Rechtsbewegungen

Greifer
Öffnen: Taste Rechteck
Schließen: Taste Kreis

Der Roboterarm besteht aus:
1. Holzarm
2. 3D-gedruckten Greifern
3. 2 SG5010 und 1 SG90 Servomotoren.
Ein Motor steuert die Greifzange, die anderen
beiden bewegen den Arm hoch und runter.

Arm
hoch: Taste Dreieck
runter: Taste X

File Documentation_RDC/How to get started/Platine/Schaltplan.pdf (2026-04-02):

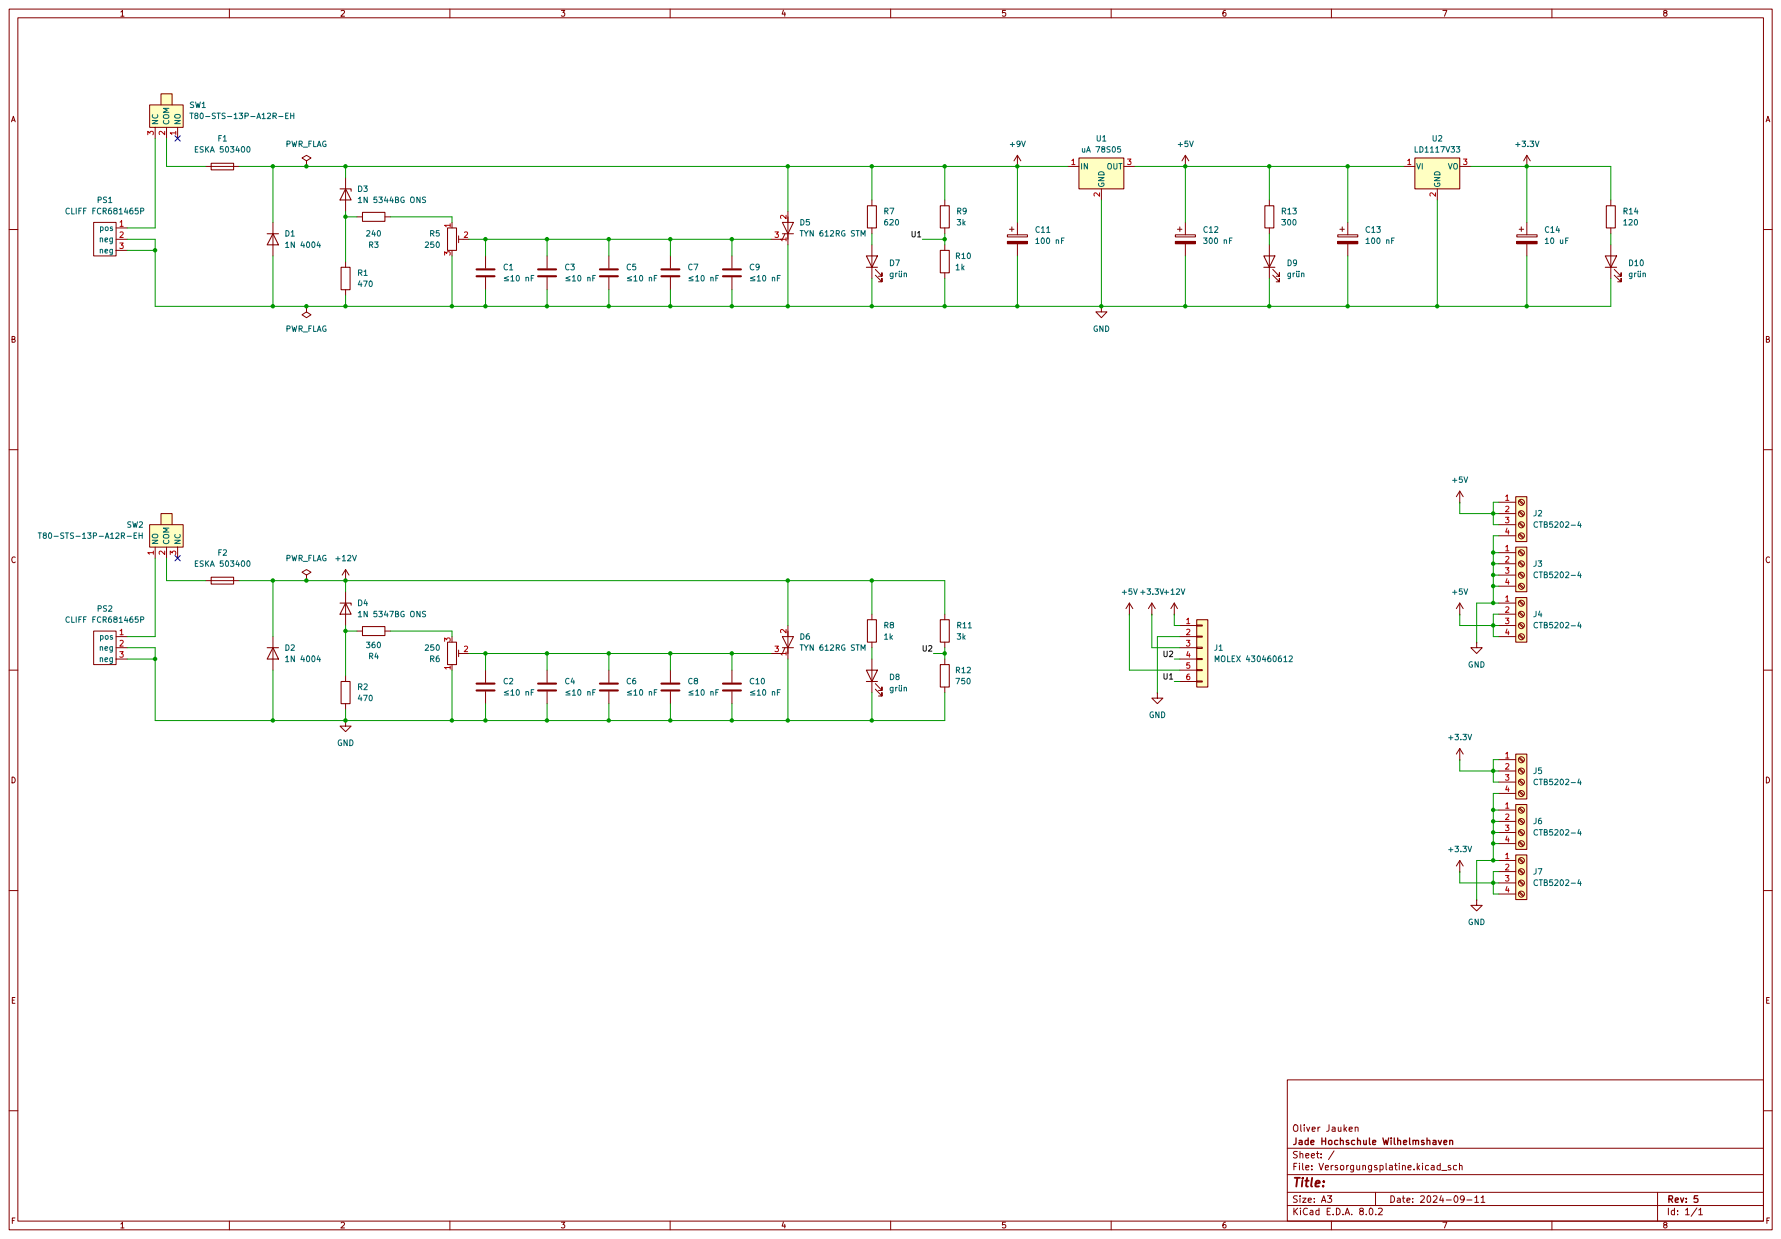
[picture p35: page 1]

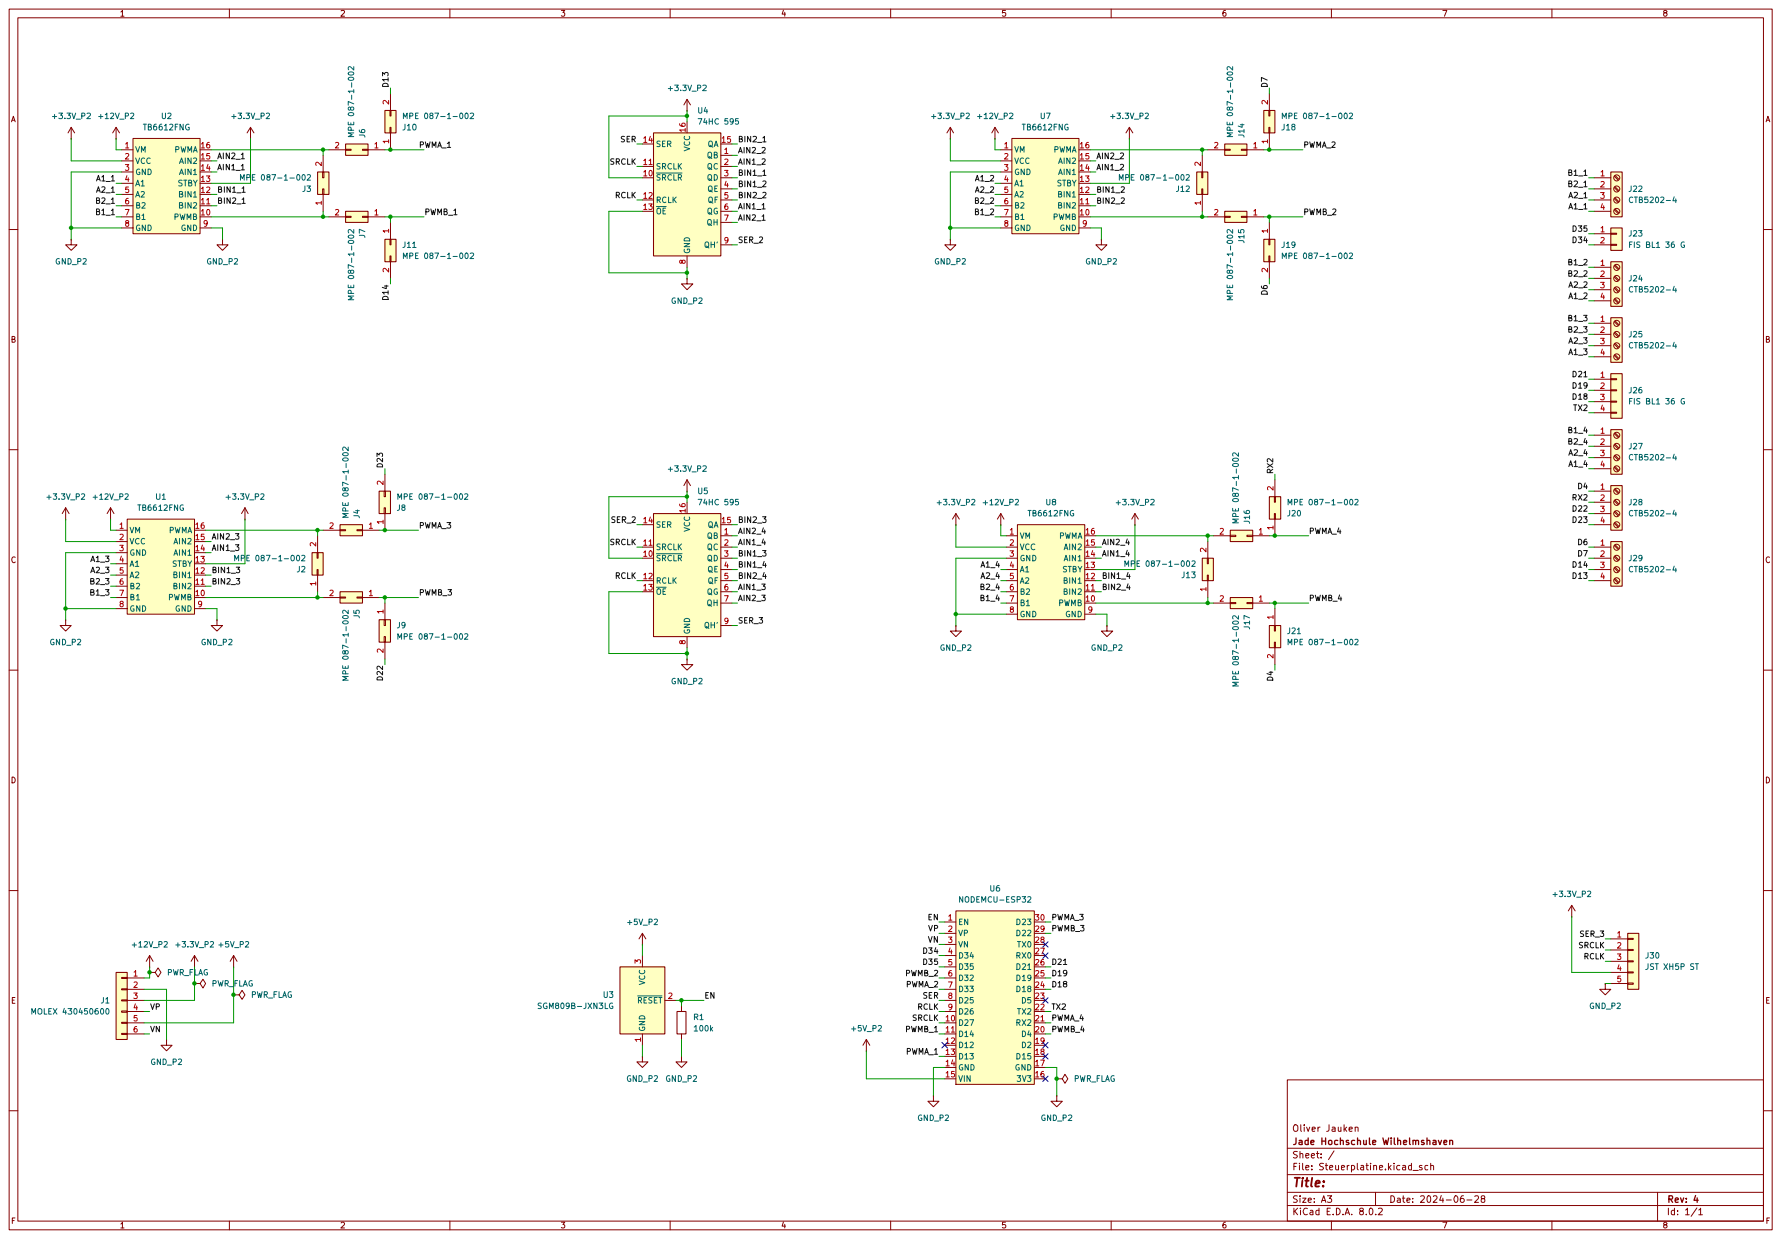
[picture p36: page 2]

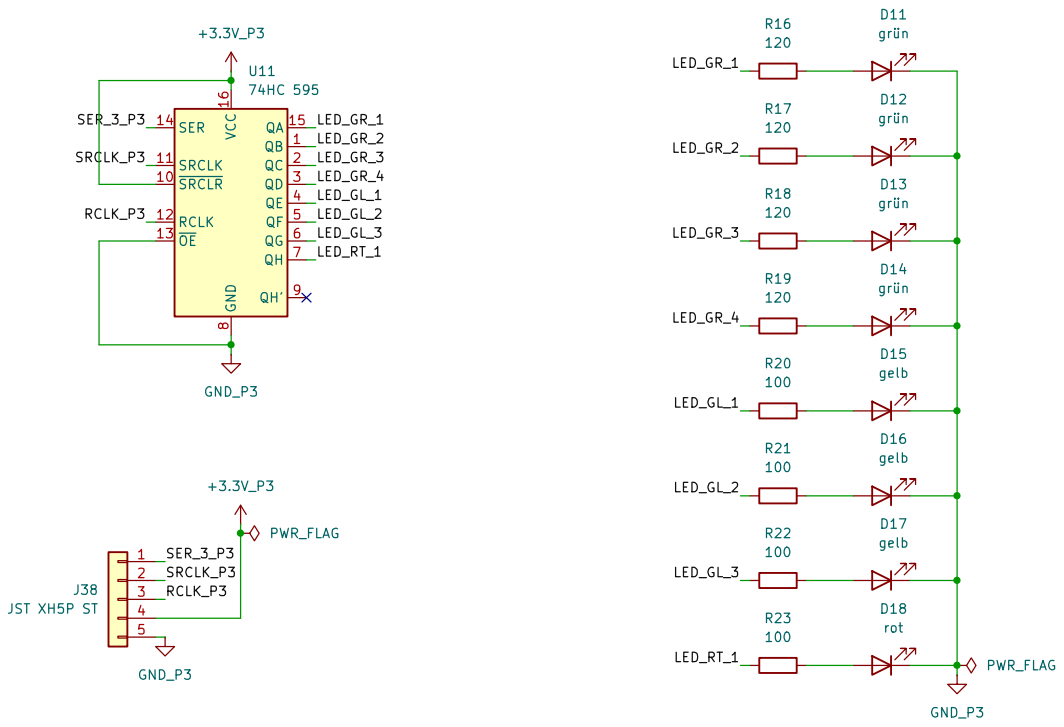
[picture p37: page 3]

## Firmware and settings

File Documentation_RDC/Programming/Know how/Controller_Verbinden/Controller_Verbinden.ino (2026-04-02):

#include <Bluepad32.h>

// MAC-Adresse, die erlaubt ist (z. B. PS4, Xbox oder Switch Pro Controller)
const bd_addr_t allowed_addr = {0xA0, 0x5A, 0x5E, 0xC9, 0x13, 0x75};

GamepadPtr myGamepad = nullptr;

// Vergleiche MAC-Adressen
bool isAddrAllowed(const bd_addr_t& addr) {
  return memcmp(addr, allowed_addr, 6) == 0;
}

void onConnectedGamepad(GamepadPtr gp) {
  const bd_addr_t& mac = gp->getProperties().btaddr;

  Serial.printf("Verbindung von: %02X:%02X:%02X:%02X:%02X:%02X\n",
                mac[0], mac[1], mac[2], mac[3], mac[4], mac[5]);

  if (isAddrAllowed(mac)) {
    Serial.println("Erlaubter Controller verbunden.");
    myGamepad = gp;
  } else {
    Serial.println("Nicht erlaubter Controller – wird getrennt.");
    delay(2000);  // Warten auf vollständige Verbindung (vermeidet GAP-Fehler)
    if (gp->isConnected()) {
      gp->disconnect();
    }
  }
}

void onDisconnectedGamepad(GamepadPtr gp) {
  Serial.println("Controller getrennt.");
  if (gp == myGamepad) {
    myGamepad = nullptr;
  }
}

void setup() {
  Serial.begin(115200);
  delay(2000);

  // Bluepad32 starten
  BP32.setup(&onConnectedGamepad, &onDisconnectedGamepad);

  // Eigene MAC-Adresse anzeigen
  const uint8_t* addr = BP32.localBdAddress();
  Serial.printf("ESP32 Bluetooth-MAC: %02X:%02X:%02X:%02X:%02X:%02X\n",
                addr[0], addr[1], addr[2], addr[3], addr[4], addr[5]);

  // Keine Allowlist-Funktionen – MAC-Filterung erfolgt im Callback
}

void loop() {
  BP32.update();

  if (myGamepad && myGamepad->isConnected()) {
    if (myGamepad->a()) {
      Serial.println("Taste A gedrückt!");
    }
  }
}

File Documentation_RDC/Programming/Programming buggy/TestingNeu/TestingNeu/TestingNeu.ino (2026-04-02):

#include <Bluepad32.h>
#include <ESP32Servo.h>

// ===== Motor & Servo Pin Setup =====
const int fR_PWM = 13;  // Front Right
const int bR_PWM = 32;  // Back Right
const int fL_PWM = 22;   // Front Left
const int bL_PWM = 16;  // Back Left

const int servoPin1 = 4;   // Base servo
const int servoPin2 = 21;   // Base servo 14
const int servoPin3 = 18;  // Gripper servo

int servo1_pos = 0;
int servo2_pos = 0;
int servo3_pos = 90;   // middle start

const int SERVO_SPEED_Greifer = 5;  // degrees per loop while holding
const int SERVO_SPEED_Base = 3;

Servo servo1;
Servo servo2;
Servo servo3;

// ===== Shift Register Pins (74HC595) =====
const uint8_t dataPin = 25;
const uint8_t clockPin = 27;
const uint8_t latchPin = 26;

uint16_t val_dri = 0;  // Motor direction bits

// ===== Bit Mapping (for direction control) =====
const uint16_t FR_fwd_BIT = (1 << 6);
const uint16_t FR_bwd_BIT = (1 << 7);
const uint16_t BR_fwd_BIT = (1 << 4);
const uint16_t BR_bwd_BIT = (1 << 5);
const uint16_t FL_fwd_BIT = (1 << 8);
const uint16_t FL_bwd_BIT = (1 << 11);
const uint16_t BL_fwd_BIT = (1 << 10);
const uint16_t BL_bwd_BIT = (1 << 9);

// ===== Controller =====
ControllerPtr myControllers[BP32_MAX_GAMEPADS];

// --- Controller connection callbacks ---
void onConnectedController(ControllerPtr ctl) {
  for (int i = 0; i < BP32_MAX_GAMEPADS; i++) {
    if (myControllers[i] == nullptr) {
      myControllers[i] = ctl;
      Serial.printf("Controller connected (index %d)\n", i);
      return;
    }
  }
  Serial.println("No free slot for controller!");
}

void onDisconnectedController(ControllerPtr ctl) {
  for (int i = 0; i < BP32_MAX_GAMEPADS; i++) {
    if (myControllers[i] == ctl) {
      myControllers[i] = nullptr;
      Serial.printf("Controller disconnected (index %d)\n", i);
      return;
    }
  }
}

// ====== Helper functions ======
void writeShiftRegister(uint16_t val) {
  digitalWrite(latchPin, LOW);
  for (int i = 0; i < 16; i++) {
    digitalWrite(clockPin, LOW);
    digitalWrite(dataPin, (val >> i) & 1);
    digitalWrite(clockPin, HIGH);
  }
  digitalWrite(latchPin, HIGH);
}

void setMotorDirection(uint16_t fwd, uint16_t bwd, int dir) {
  val_dri &= ~(fwd | bwd);  // Clear
  if (dir == 1)
    val_dri |= fwd;
  else if (dir == -1)
    val_dri |= bwd;
}

void updateMotors(int leftSpeed, int rightSpeed) {
  leftSpeed = constrain(leftSpeed, 0, 255);
  rightSpeed = constrain(rightSpeed, 0, 255);
  analogWrite(fL_PWM, leftSpeed);
  analogWrite(bL_PWM, leftSpeed);
  analogWrite(fR_PWM, rightSpeed);
  analogWrite(bR_PWM, rightSpeed);
}

// ====== Main Controller Processing ======
void processGamepad(ControllerPtr ctl) {
  int LX = ctl->axisX();
  int LY = ctl->axisY();

  // Testing
  // forward
  if (ctl->dpad() == 0x01)
  {
    int speed = 200;
    setMotorDirection(FR_fwd_BIT, FR_bwd_BIT, 1);
    setMotorDirection(FL_fwd_BIT, FL_bwd_BIT, 1);
    setMotorDirection(BR_fwd_BIT, BR_bwd_BIT, 1);
    setMotorDirection(BL_fwd_BIT, BL_bwd_BIT, 1);
    updateMotors(speed, speed);
  }
  //backward
  else if (ctl->dpad() == 0x02)
  {
    int speed = 200;
    setMotorDirection(FR_fwd_BIT, FR_bwd_BIT, -1);
    setMotorDirection(FL_fwd_BIT, FL_bwd_BIT, -1);
    setMotorDirection(BR_fwd_BIT, BR_bwd_BIT, -1);
    setMotorDirection(BL_fwd_BIT, BL_bwd_BIT, -1);
    updateMotors(speed, speed);
  }
  // left
  else if (ctl->dpad() == 0x08)
  {
    int speed = 150;
    setMotorDirection(FR_fwd_BIT, FR_bwd_BIT, -1);
    setMotorDirection(FL_fwd_BIT, FL_bwd_BIT, 1);
    setMotorDirection(BR_fwd_BIT, BR_bwd_BIT, -1);
    setMotorDirection(BL_fwd_BIT, BL_bwd_BIT, 1);
    updateMotors(speed, speed);
  }
  //right
  else if (ctl->dpad() == 0x04)
  {
    int speed = 150;
    setMotorDirection(FR_fwd_BIT, FR_bwd_BIT, 1);
    setMotorDirection(FL_fwd_BIT, FL_bwd_BIT, -1);
    setMotorDirection(BR_fwd_BIT, BR_bwd_BIT, 1);
    setMotorDirection(BL_fwd_BIT, BL_bwd_BIT, -1);
    updateMotors(speed, speed);
  }
  else
  {
    updateMotors(0,0);
  }    

  // ================= SERVO CONTROL =================

// ----- Servo 1 (Base) -----
if (ctl->buttons() == 0x0008) {   // traingle (down)
    servo1_pos = constrain(servo1_pos + SERVO_SPEED_Base, 0, 60);
}
if (ctl->buttons() == 0x0001) {   // X (up)
    servo1_pos = constrain(servo1_pos - SERVO_SPEED_Base, 0, 60);
}
servo1.write(servo1_pos);

// ----- Servo 2 (Base) -----
if (ctl->buttons() == 0x0008) {
    servo2_pos = constrain(servo2_pos + SERVO_SPEED_Base, 0, 60);
}
if (ctl->buttons() == 0x0001) {
    servo2_pos = constrain(servo2_pos - SERVO_SPEED_Base, 0, 60);
}
servo2.write(servo2_pos);

// ----- Servo 3 (Greifer) -----
if (ctl->buttons() == 0x0002) {    // Circle (close)
    servo3_pos = constrain(servo3_pos + SERVO_SPEED_Greifer, 0, 180);
}
if (ctl->buttons() == 0x0004) {   // Square (open)
    servo3_pos = constrain(servo3_pos - SERVO_SPEED_Greifer, 0, 180);
}
servo3.write(servo3_pos);

  writeShiftRegister(val_dri);
}

// ====== Controller Loop ======
void processControllers() {
  for (auto ctl : myControllers) {
    if (ctl && ctl->isConnected() && ctl->hasData() && ctl->isGamepad())
      processGamepad(ctl);
  }
}

// ====== Setup ======
void setup() {
  Serial.begin(115200);
  pinMode(fR_PWM, OUTPUT);
  pinMode(bR_PWM, OUTPUT);
  pinMode(fL_PWM, OUTPUT);
  pinMode(bL_PWM, OUTPUT);
  pinMode(dataPin, OUTPUT);
  pinMode(clockPin, OUTPUT);
  pinMode(latchPin, OUTPUT);

  servo1.attach(servoPin1);
  servo2.attach(servoPin2);
  servo3.attach(servoPin3);

  Serial.printf("Firmware: %s\n", BP32.firmwareVersion());
  const uint8_t* addr = BP32.localBdAddress();
  Serial.printf("BD Addr: %2X:%2X:%2X:%2X:%2X:%2X\n", addr[0], addr[1], addr[2], addr[3], addr[4], addr[5]);

  BP32.setup(&onConnectedController, &onDisconnectedController);
  BP32.forgetBluetoothKeys();
  BP32.enableVirtualDevice(false);

  Serial.println("Robot ready. Connect your PS4 controller!");
}

// ====== Loop ======
void loop() {
  if (BP32.update())
    processControllers();
  delay(50);
}
